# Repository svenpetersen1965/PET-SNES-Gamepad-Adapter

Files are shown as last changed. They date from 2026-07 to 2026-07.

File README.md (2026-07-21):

# PET-SNES-Gamepad-Adapter
An Adapter for connecting the SNES Gamepad to the userport of the Commodore PET/CBM/C64/VIC20

This adapter is capable of playing PETSCII robots and other SNES Gamepad compatible games on the Commodore PET. It was further tested playing the forementioned game on the C64.

There is a Rev. 1, which can be switched to use the +5V of the C64 User Port, so no diagnostic cassette dongle or external PSU is required for powering the gamepad. 

<b>!!!WARNING: Setting the power selection switch to C64 and connect the device to a PET might damage the computer!!!</b> 

It is recommended to leave the switch not populated in case you are planning to coonect the device to a PET. If you have a PET, check the setting each time, before you connect ther device to the PET. 

Recommended screws:<br>
Four each of 2.9mm x 9.5mm (self taping) screws for sheet metal (C 2,9x9,5H, DIN 7981).

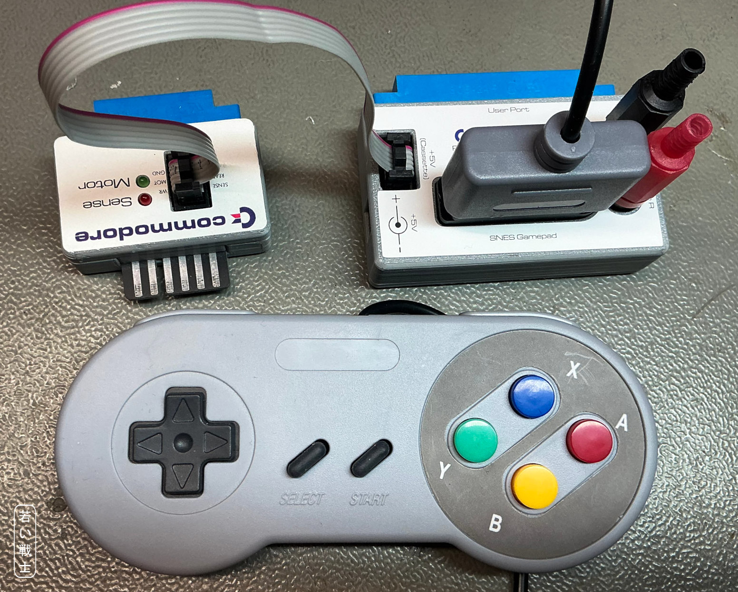
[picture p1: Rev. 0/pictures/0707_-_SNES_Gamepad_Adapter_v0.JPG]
PET SNES Gamepad Adapter Rev.0


The BOM value of Rev. 1 is 14,95€ (2026-07-21) without the cassette dongle, a case and or shipping fees or tariffs .

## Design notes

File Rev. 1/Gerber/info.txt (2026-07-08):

      
       Board: PET_SNES_Gamepad
       Rev.:  1
  
       Files:
       ======
  
       All Gerber files are generated in extended gerber format (RS274X)
       *.TOP        : Film top copper
       *.BOT        :  -"- bottom copper
       *.STC        :  -"- top soldermask 
       *.STS        :  -"- bottom soldermask
       *.PLC        :  -"- silk screen top
       *.PLS        :  -"- silk screen bottom 
       *.DK         : Drills plated Through (Excellon)
       *.NDK        : Drills not plated Through (Excellon)
       *.OUT        : Board outline

       Board Size:
       ===========
       Length     :   71.0 mm
       Width      :   43.0 mm
       Thickness  :   1.6 mm
       Material   :   FR 4
       Copper     :   35 um
       Surface    :   HASL
       
       Remarks:
       ========
       Width >= 8mil
       Distance >= 6mil
       Drill >= 0.35mm

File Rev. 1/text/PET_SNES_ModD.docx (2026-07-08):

SNES Gamepad Adapter for Commodore PET Rev.1

Module Description

# Introduction

The SNES Gamepad Adapter for PET works with the respective games found on Bo Zimmerman’s website zimmers.net and PETSCII robots by the 8bit guy.

The source of information about the hardware requirements is the file snes_adapter.zip from zimmers.net (https://www.zimmers.net/anonftp/pub/cbm/documents/projects/interfaces/index.html). A further source was https://wiki.superfamicom.org/schematics-ports-and-pinouts#. The zimmers.net file contains references to texelex.com and Steve Lewis plus source code in C and BASIC for polling the gamepad.

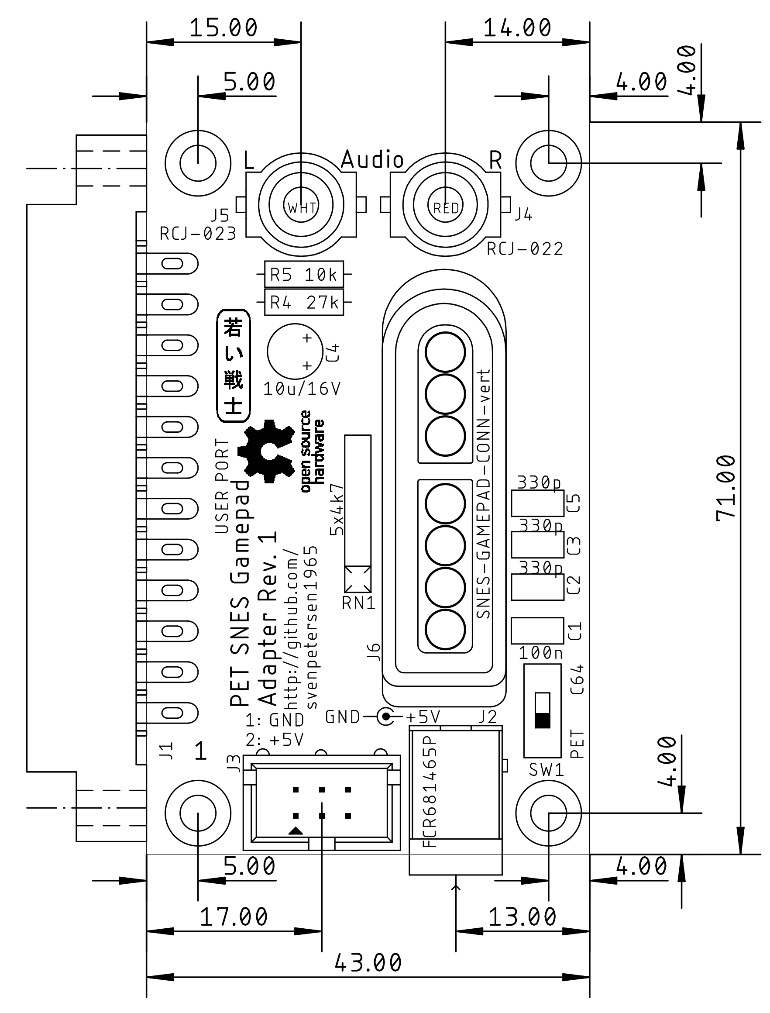
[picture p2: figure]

Figure 1: PET SNES Gamepad Adapter Rev. 0 (Dimensions)

Since the PET User Port does not provide +5V supply voltage, there is a 6 was box pin header form connecting a cassette port dongle (https://github.com/svenpetersen1965/C64-Diagnostic-Rev.-586220-Harness/tree/master/Diag586220_Harness/Diag586220_Cassette_Port) (where +5V can be tapped for the Gamepad. This is the recommended solution. Further, there is a 5.5mm/2.1mm barrel connector for a +5V external PSU. For the C64, the switch SW1 can be set to “C64” to use the +5V from the C64 User Port.

WARNING: Never connect to board to a PET with SW1 in the C64 position, since this might cause damage to the PET.

The CB2 audio is tapped from the user port and connected to two RCA jacks via a voltage divider and a capacitor for connecting external PC speakers.

The adapter works with PETSCII Robots for the C64, as well. Since the 5V of the C64 are not connected (that would be the TVVIDEO pin of the user port), either a Cassette Port Dongle or an external Power Supply is required.

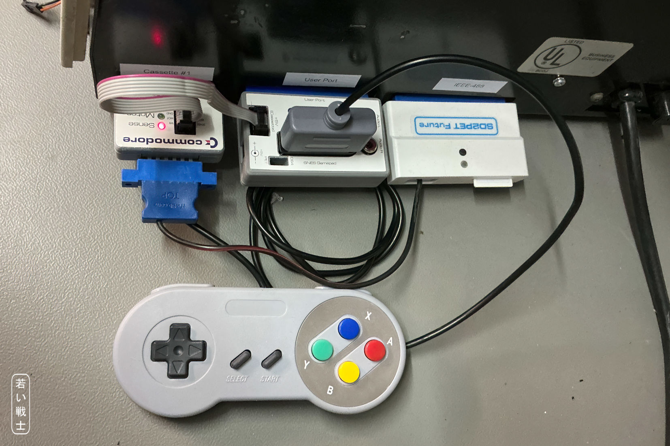
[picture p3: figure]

Figure 2: Backside of a CBM8032 - SNES Adapter with Cassette Port Dongle (and SD2PET Future)

# Switch SW1

Since connecting the PET SNES Gamepad Adapter to a PET, while SW1 is set to “C64” can damage the PET, it should be considered well, if SW1 is installed.

SW1 is for using the +5V from the C64 User Port instead of the diagnostic cassette dongle or an external +5V power supply. If SW1 is not placed, the board works exactly like Rev. 0 (with the previously mentioned options for the supply voltage and a Rev. 0 case). It is recommended to install the switch only, in case the adapter is used only with a C64.

# Pinouts

## J1- User Port

2x12 Edge Connector, 3.96mm pitch

Pin | Signal | Gamepad
1, 12, A, N | GND | GND
3 | +5V | C64 only: +5V
F | PA3 | Clock
J | PA5 | Latch
K | PA6 | Data

## 2 – Power Supply Connector

5,5mm/2,5mm barrel connector (Cliff FCR681465P)

Pin | Signal
Center | +5VDC
Shaft | GND

This is an alternative power connector, which can be used with an external +5V power supply. It is not the preferred way of powering the module.

## J3 - Power connector (from cassette port)

2x3 pin box connector

Signal | Pin | Pin | Signal
GND | 1 | 2 | +5V
- | 3 | 4 | -
- | 5 | 6 | -

Powering from cassette port is the preferred way, since it switches off together with the PET. This requires a Cassette Port Dongle (see C64 Diagnostic harness (https://github.com/svenpetersen1965/C64-Diagnostic-Rev.-586220-Harness)).

## J4, J5 – Audio RCA jacks

2 vertical RCA jacks

Connector | Color | Center | Ring | Type
J4 | Red | Audio | GND | CUI Inc. RCJ-022
J5 | White | Audio | GND | CUI Inc. RCJ-023

Note: The CUI Inc connectors are pretty wide spread and available from Mouser and Digikey etc. There are acceptable and cheaper connectors from AliExpress, which perfectly fit into the footprint. Click URL (https://de.aliexpress.com/item/1005004200016377.html)

Both connectors are connected to the same source. The audio level is about 1.23V~ (+4dBu).

## J6 – SNES Gamepad

SNES Gamepad Connector (vertical)

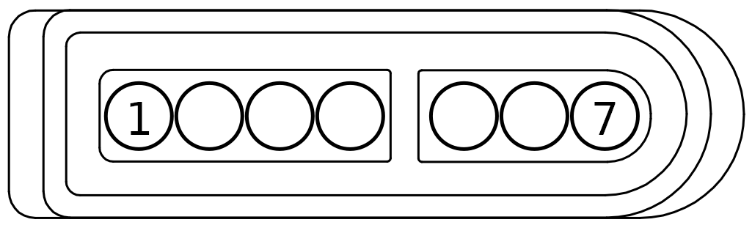
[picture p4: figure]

Figure 3: SNES Gamepad Connector

Pin | Signal
1 | +5V
2 | Clock
3 | Latch
4 | Data1
5 | Data2 (not connected)
6 | IOBIT (not connected)
7 | GND

# Case

There is a 3D printed case and a case label for Rev. 1. In case SW1 is not placed, please use case and label for the PCB Rev. 0

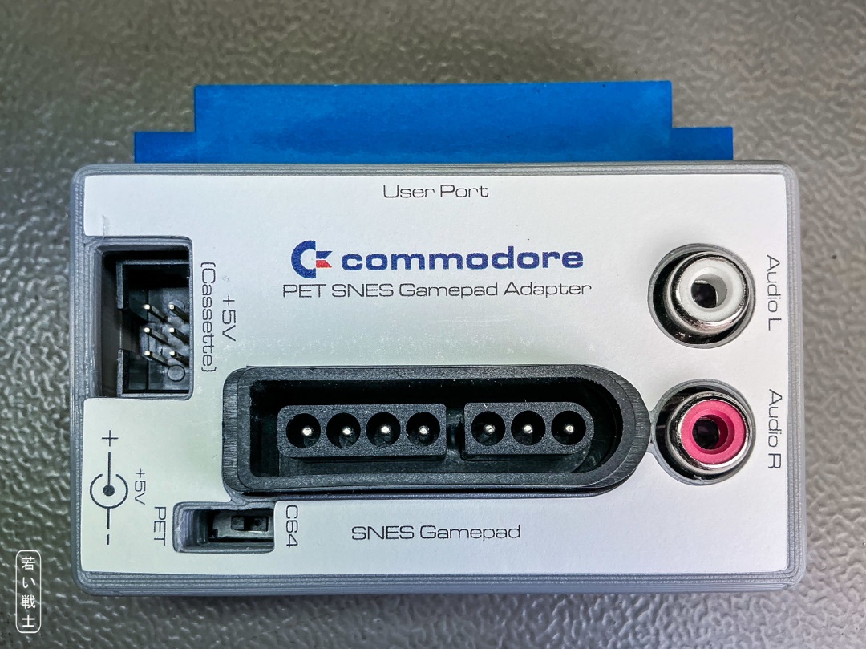
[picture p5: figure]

Figure 4: PET SNES Gamepad Adapter (in case)

# Programming Hints

First, the data direction register of the user port needs to be set correctly. Clock (bit #3) and Latch (bit#5) are outputs of the user port, Data (bit#6) is an input:

POKE 59459,8+32

While scanning the gamepad, a (positive) latch pulse is required first:

POKE59457,32:POKE59457,0:REM LATCH PULSE

The gamepad outputs a 12 bit word, MSB first. After the latch pulse, the MSB is present at the data input (bit#6) of the user port.

GW=0:B=2048
FOR I=12 TO 1 STEP-1
IF PEEK(59457) AND 64 THEN GW=GW+B:REM IS BIT#6 SET?
B=B/2
POKE59457,8:POKE59457,0:REM PULSE CLOCK
NEXT I

An active data bit is LOW, this is, why it needs to be inverted

GW=4096 + NOT GW:REM INVERT GW

Now, the gamepad word can be decoded:

Bit | Bit Value | Gamepad
0 | 1 | Fire-R
1 | 2 | Fire-L
2 | 4 | X
3 | 8 | A
4 | 16 | Right
5 | 32 | Left
6 | 64 | Down
7 | 128 | Up
8 | 256 | Start
9 | 512 | Select
10 | 1024 | Y
11 | 2048 | B

The source is SNES TEST.BAS.PRG from the previously mentioned file snes_adapter.zip

# Revision History

## Rev. 0

Prototype, tested ok

## Rev. 1

- SW1 for switching on the +5V from the C64 User Port.

PET_SNES_ModD.docx 08.07.2026 15:50 Drafted by Sven Petersen Page 2 of 2 Doc.-No.: 221-6-01-01

PET_SNES_ModD.docx 08.07.2026 15:50 Drafted by Sven Petersen Page 1 of 1 Doc.-No.: 221-6-01-01

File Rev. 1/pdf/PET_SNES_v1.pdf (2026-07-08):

# Project Documentation

## PET SNES Gamepad Adapter

## Project number: 221

## Revision: 1

## Date: 10.05.2026

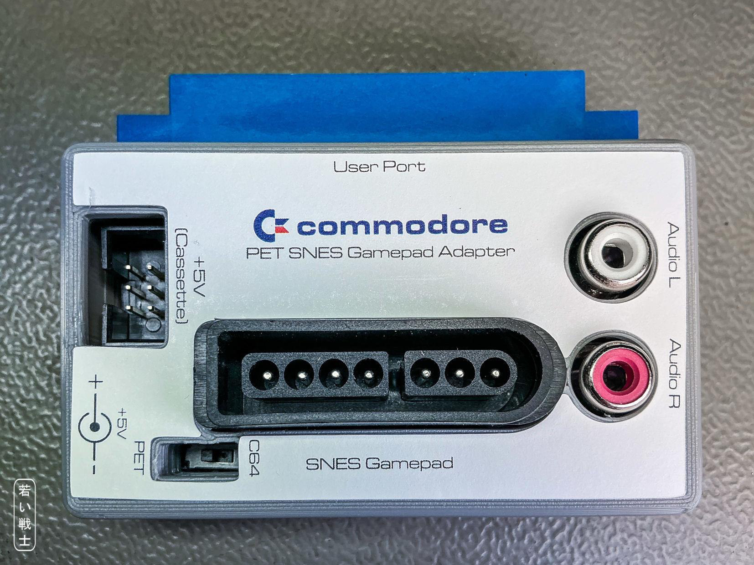
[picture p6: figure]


PET_SNES_ModD.docx | | 08.07.2026 15:50
Drafted by Sven Petersen | Page 1 of 5 | Doc.-No.: 221-6-01-01

### SNES Gamepad Adapter for Commodore PET Rev.1

### Module Description

## Introduction

The SNES Gamepad Adapter for PET works with the respective games found on Bo Zimmerman’s website zimmers.net and PETSCII robots by the 8bit guy.

The source of information about the hardware requirements is the file snes_adapter.zip from zimmers.net. (https://www.zimmers.net/anonftp/pub/cbm/documents/projects/interfaces/index.html) A further source was https://wiki.superfamicom.org/schematics-ports-and-pinouts#. (https://wiki.superfamicom.org/schematics-ports-and-pinouts) The zimmers.net file contains references to texelex.com and Steve Lewis plus source code in C and BASIC for polling the gamepad.

Figure 1: PET SNES Gamepad Adapter Rev. 0 (Dimensions)

Since the PET User Port does not provide +5V supply voltage, there is a 6 was box pin header form connecting a cassette port dongle (https://github.com/svenpetersen1965/C64-Diagnostic-Rev.-586220-Harness/tree/master/Diag586220_Harness/Diag586220_Cassette_Port) (where +5V can be tapped for the Gamepad. This is the recommended solution. Further, there is a 5.5mm/2.1mm barrel connector for a +5V external PSU.
For the C64, the switch SW1 can be set to “C64” to use the +5V from the C64 User Port.

WARNING: Never connect to board to a PET with SW1 in the C64 position, since this might cause damage to the PET.

The CB2 audio is tapped from the user port and connected to two RCA jacks via a voltage divider and a capacitor for connecting external PC speakers.

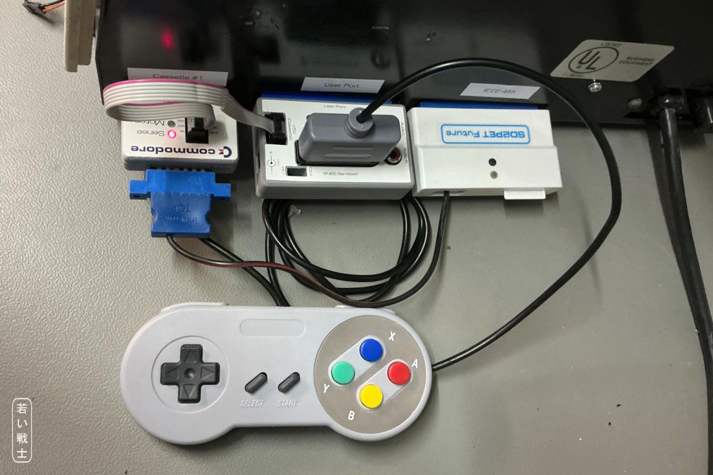
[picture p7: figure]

PET_SNES_ModD.docx | | 08.07.2026 15:50
Drafted by Sven Petersen | Page 2 of 5 | Doc.-No.: 221-6-01-01

The adapter works with PETSCII Robots for the C64, as well. Since the 5V of the C64 are not connected (that would be the TVVIDEO pin of the user port), either a Cassette Port Dongle or an external Power Supply is required.

Figure 2: Backside of a CBM8032 - SNES Adapter with Cassette Port Dongle (and SD2PET Future)

## Switch SW1

### Since connecting the PET SNES Gamepad Adapter to a PET, while SW1 is set to “C64” can

damage the PET, it should be considered well, if SW1 is installed.

SW1 is for using the +5V from the C64 User Port instead of the diagnostic cassette dongle or an external +5V power supply. If SW1 is not placed, the board works exactly like Rev. 0 (with the previously mentioned options for the supply voltage and a Rev. 0 case). It is recommended to install the switch only, in case the adapter is used only with a C64.

## Pinouts

### J1- User Port

2x12 Edge Connector, 3.96mm pitch

Pin | Signal | Gamepad
1, 12, A, N | GND | GND
3 | +5V | C64 only: +5V
F | PA3 | Clock
J | PA5 | Latch
K | PA6 | Data

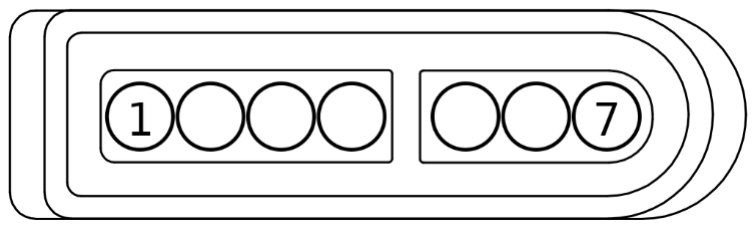
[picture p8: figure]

PET_SNES_ModD.docx | | 08.07.2026 15:50
Drafted by Sven Petersen | Page 3 of 5 | Doc.-No.: 221-6-01-01

### 2 – Power Supply Connector

5,5mm/2,5mm barrel connector (Cliff FCR681465P)

Pin | Signal
Center | +5VDC
Shaft | GND
This is an alternative power connector, which can be used with an external +5V power supply. It is not the preferred way of powering the module.

### J3 - Power connector (from cassette port)

2x3 pin box connector

Signal Pin | Pin Signal
GND | 1 | 2 | +5V
- | 3 | 4 | -
- | 5 | 6 | -

Powering from cassette port is the preferred way, since it switches off together with the PET. This requires a Cassette Port Dongle (see C64 Diagnostic harness). (https://github.com/svenpetersen1965/C64-Diagnostic-Rev.-586220-Harness)

### J4, J5 – Audio RCA jacks

2 vertical RCA jacks

Connector | Color | Center | Ring | Type
J4 | Red | Audio | GND | CUI Inc. RCJ-022
J5 | White | Audio | GND | CUI Inc. RCJ-023

Note: The CUI Inc connectors are pretty wide spread and available from Mouser and Digikey etc. There are acceptable and cheaper connectors from AliExpress, which perfectly fit into the footprint. Click URL (https://de.aliexpress.com/item/1005004200016377.html)

Both connectors are connected to the same source. The audio level is about 1.23V~ (+4dBu).

### J6 – SNES Gamepad

SNES Gamepad Connector (vertical)

Figure 3: SNES Gamepad Connector

Pin | Signal
1 | +5V
2 | Clock
3 | Latch
4 | Data1
5 | Data2 (not connected)
6 | IOBIT (not connected)
7 | GND

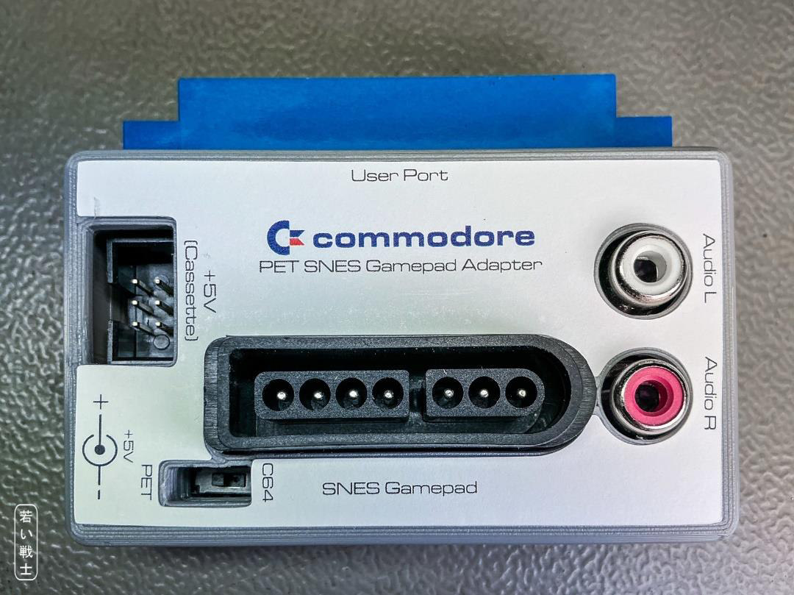
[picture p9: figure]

PET_SNES_ModD.docx | | 08.07.2026 15:50
Drafted by Sven Petersen | Page 4 of 5 | Doc.-No.: 221-6-01-01

## Case

There is a 3D printed case and a case label for Rev. 1. In case SW1 is not placed, please use case and label for the PCB Rev. 0

Figure 4: PET SNES Gamepad Adapter (in case)

## Programming Hints

First, the data direction register of the user port needs to be set correctly. Clock (bit #3) and Latch (bit#5) are outputs of the user port, Data (bit#6) is an input:

POKE 59459,8+32

While scanning the gamepad, a (positive) latch pulse is required first:

POKE59457,32:POKE59457,0:REM LATCH PULSE

The gamepad outputs a 12 bit word, MSB first. After the latch pulse, the MSB is present at the data input (bit#6) of the user port.

GW=0:B=2048
FOR I=12 TO 1 STEP-1
IF PEEK(59457) AND 64 THEN GW=GW+B:REM IS BIT#6 SET? B=B/2
POKE59457,8:POKE59457,0:REM PULSE CLOCK
NEXT I

PET_SNES_ModD.docx | | 08.07.2026 15:50
Drafted by Sven Petersen | Page 5 of 5 | Doc.-No.: 221-6-01-01

An active data bit is LOW, this is, why it needs to be inverted

GW=4096 + NOT GW:REM INVERT GW

Now, the gamepad word can be decoded:

Bit | Bit Value | Gamepad
0 | 1 | Fire-R
1 | 2 | Fire-L
2 | 4 | X
3 | 8 | A
4 | 16 | Right
5 | 32 | Left
6 | 64 | Down
7 | 128 | Up
8 | 256 | Start
9 | 512 | Select
10 | 1024 | Y
11 | 2048 | B

The source is SNES TEST.BAS.PRG from the previously mentioned file snes_adapter.zip

## Revision History

### Rev. 0

Prototype, tested ok

### Rev. 1

- SW1 for switching on the +5V from the C64 User Port.

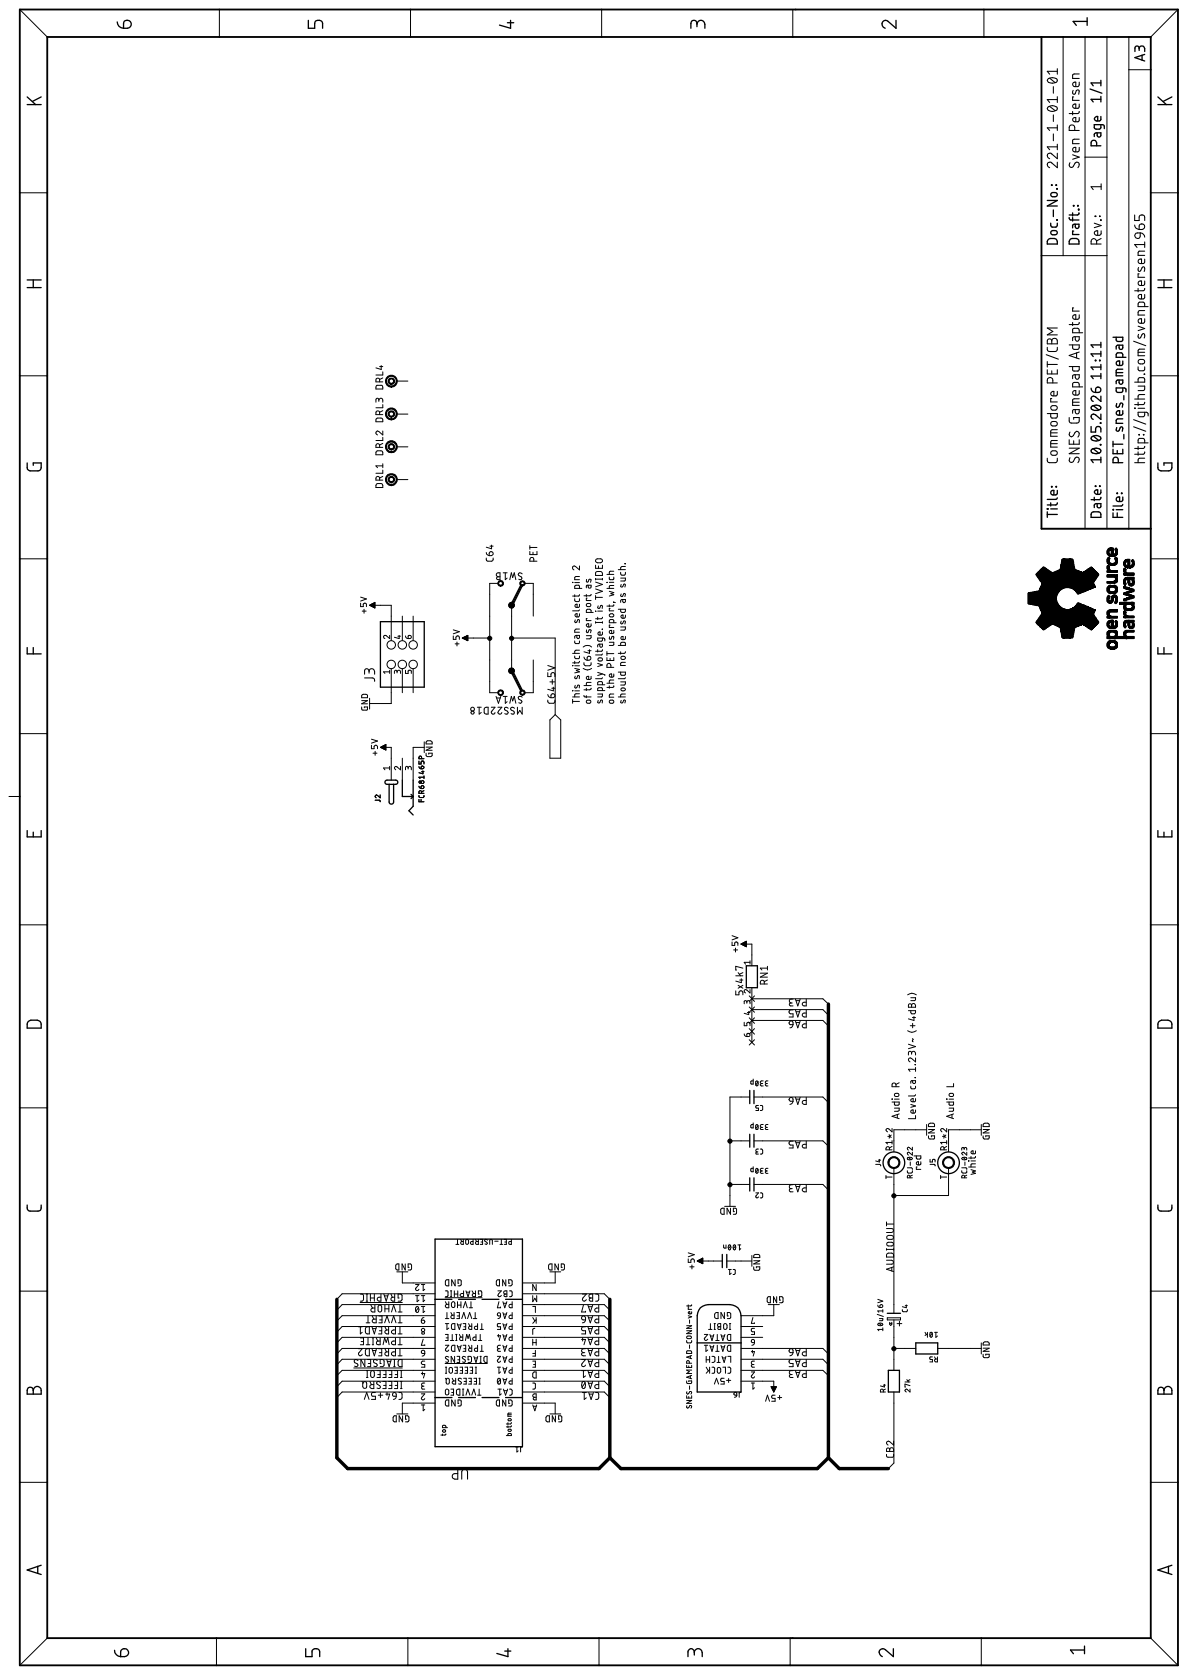
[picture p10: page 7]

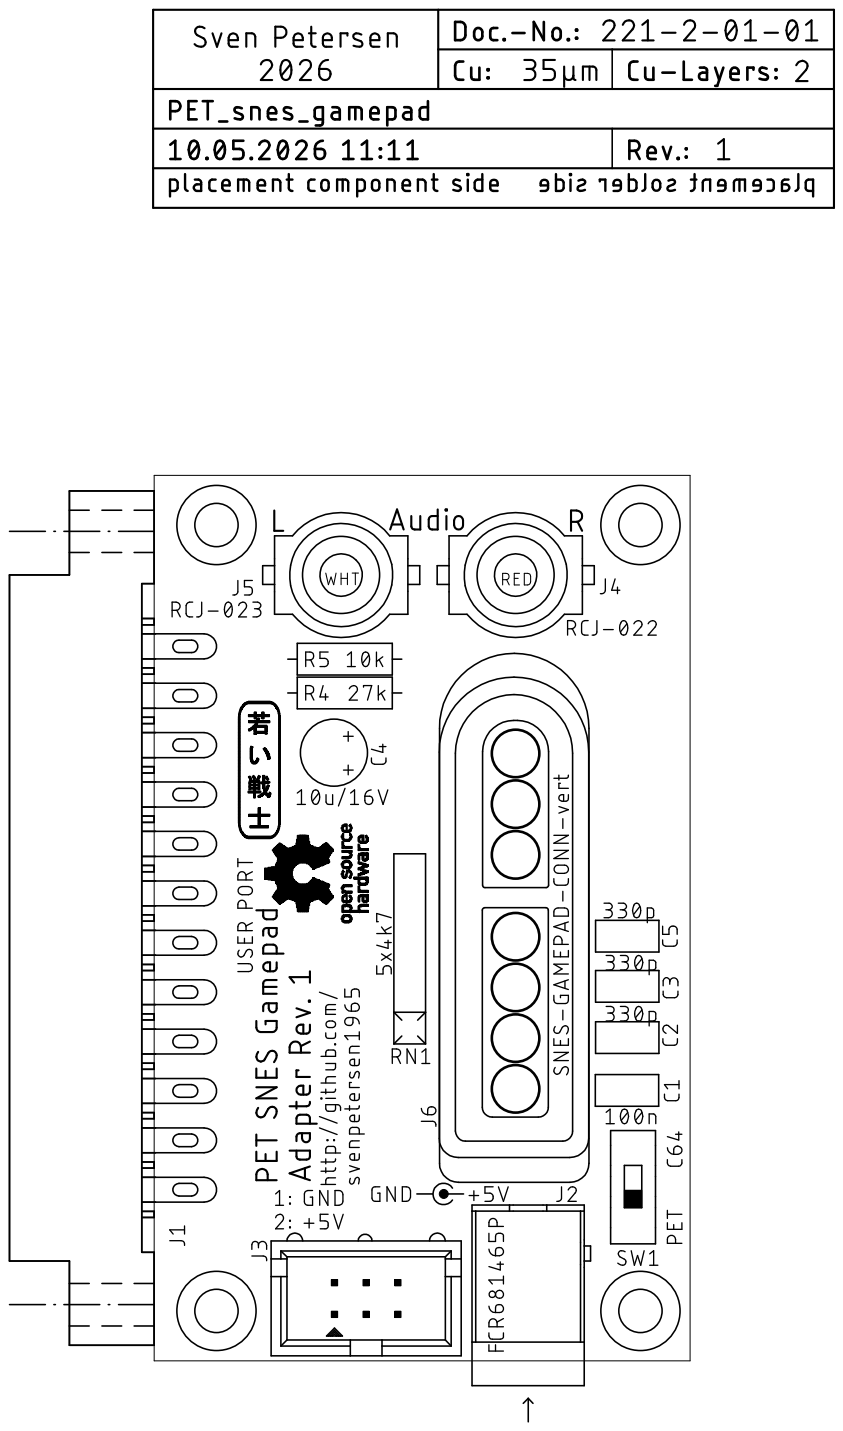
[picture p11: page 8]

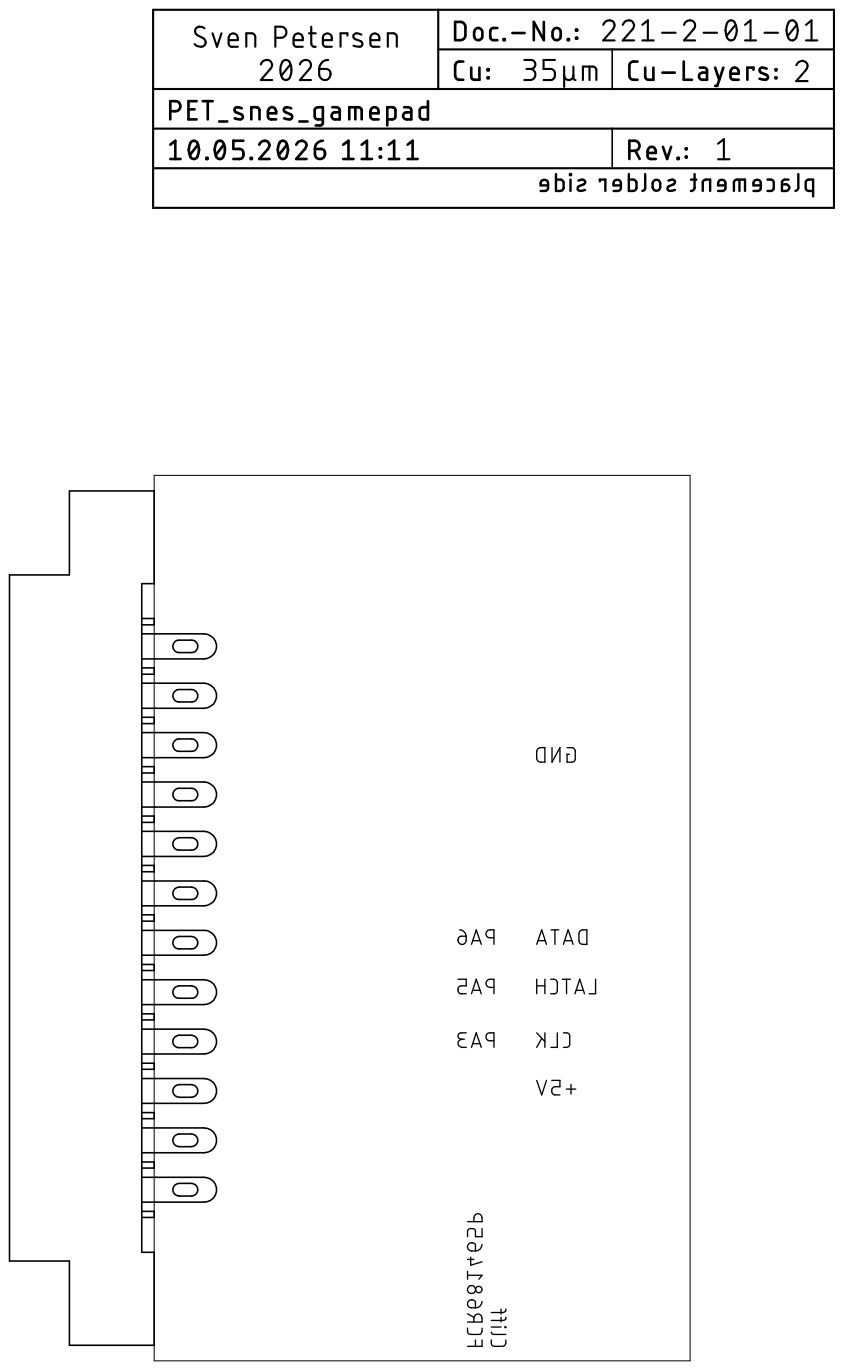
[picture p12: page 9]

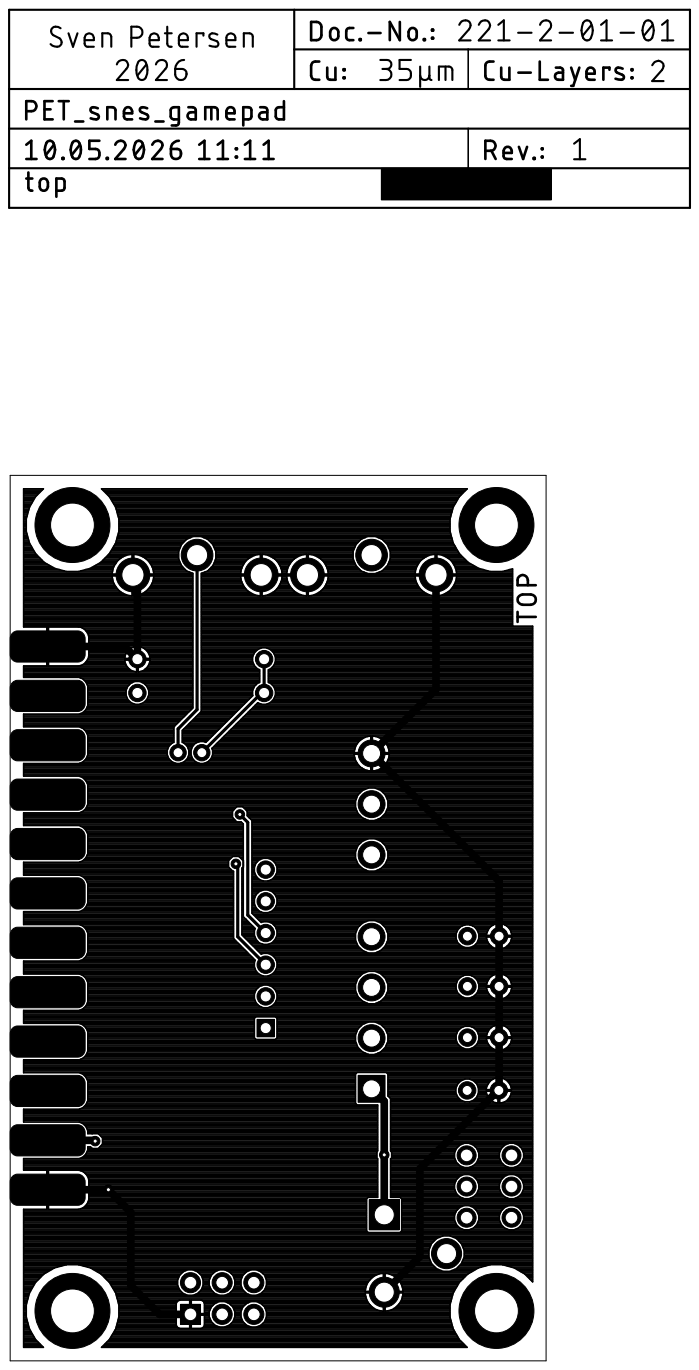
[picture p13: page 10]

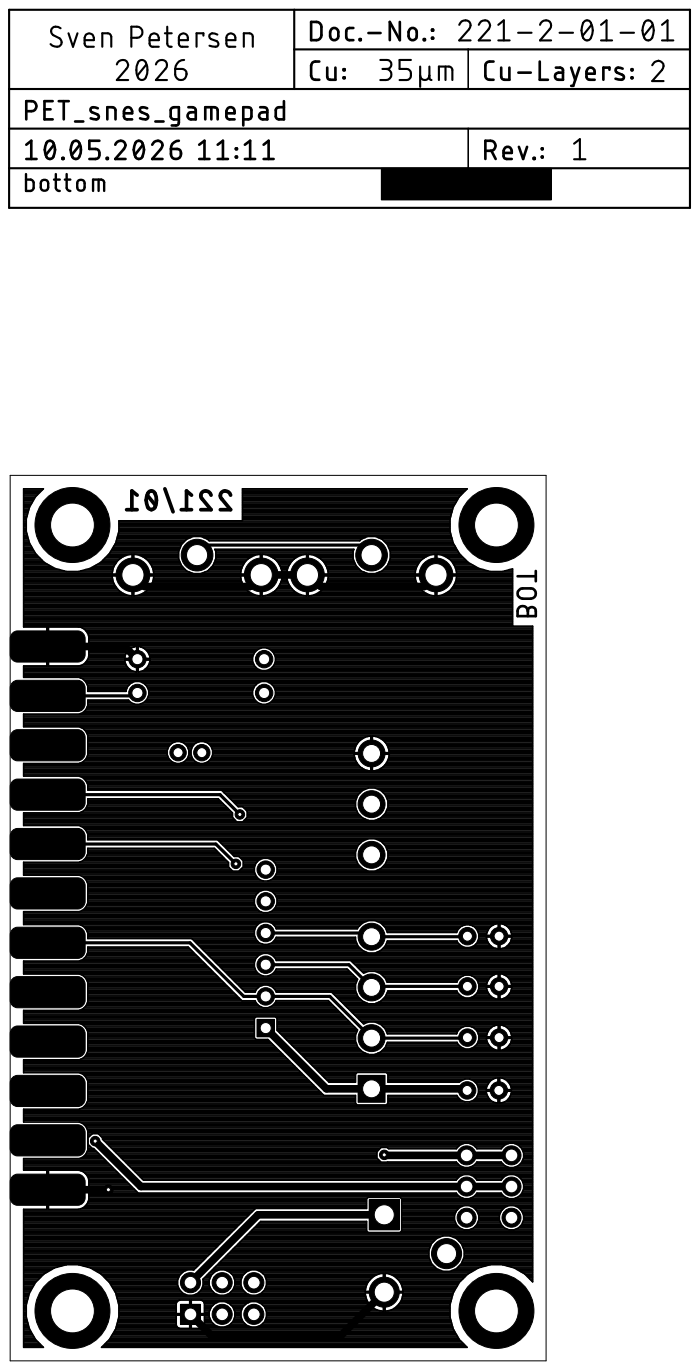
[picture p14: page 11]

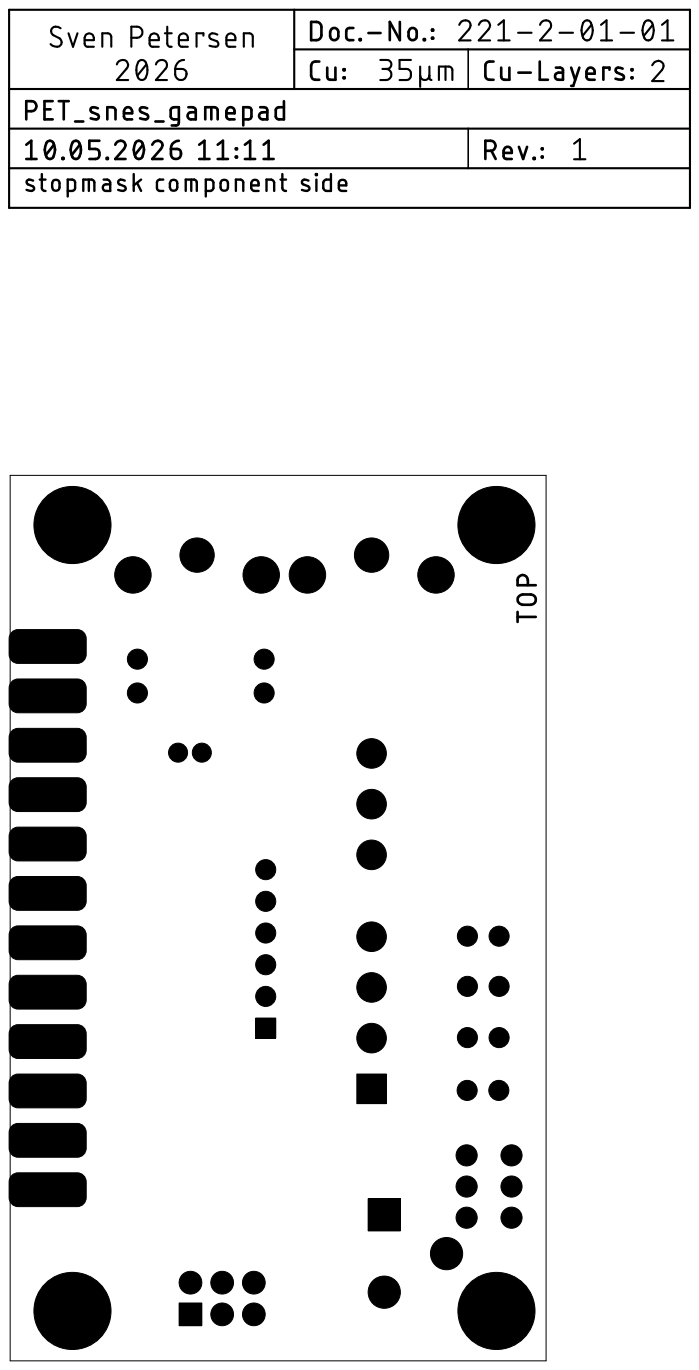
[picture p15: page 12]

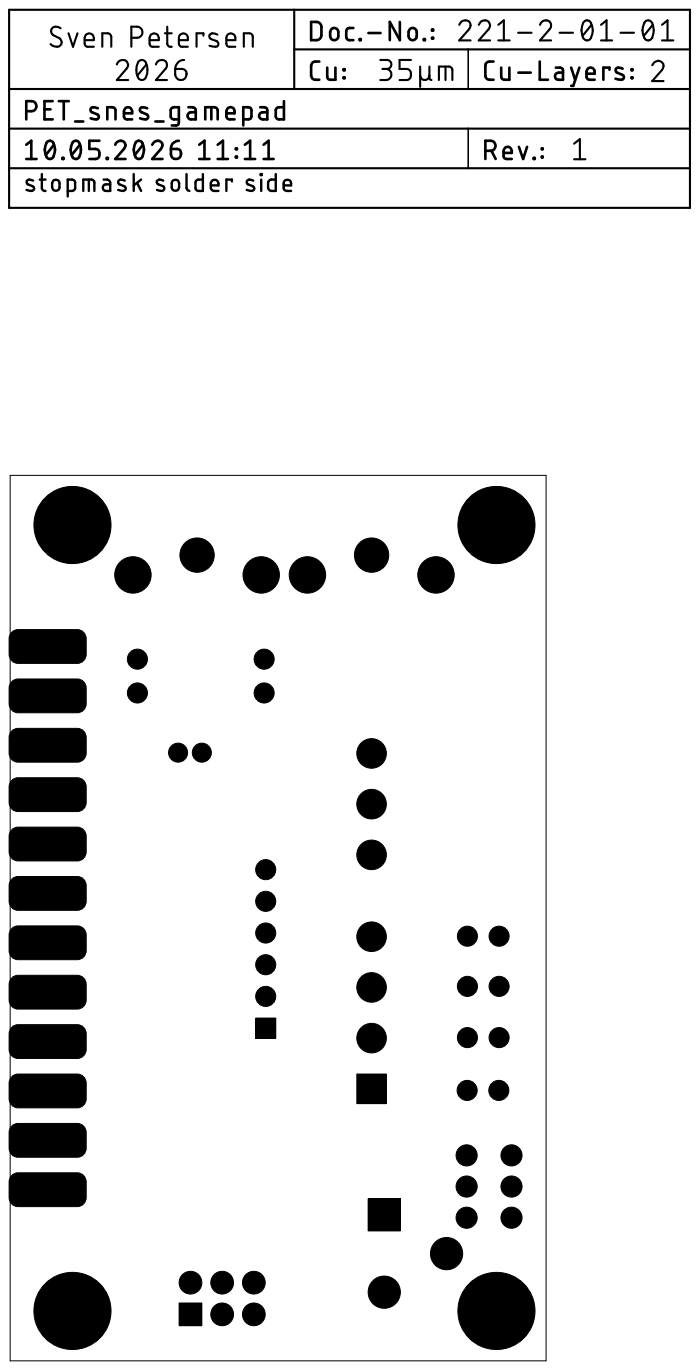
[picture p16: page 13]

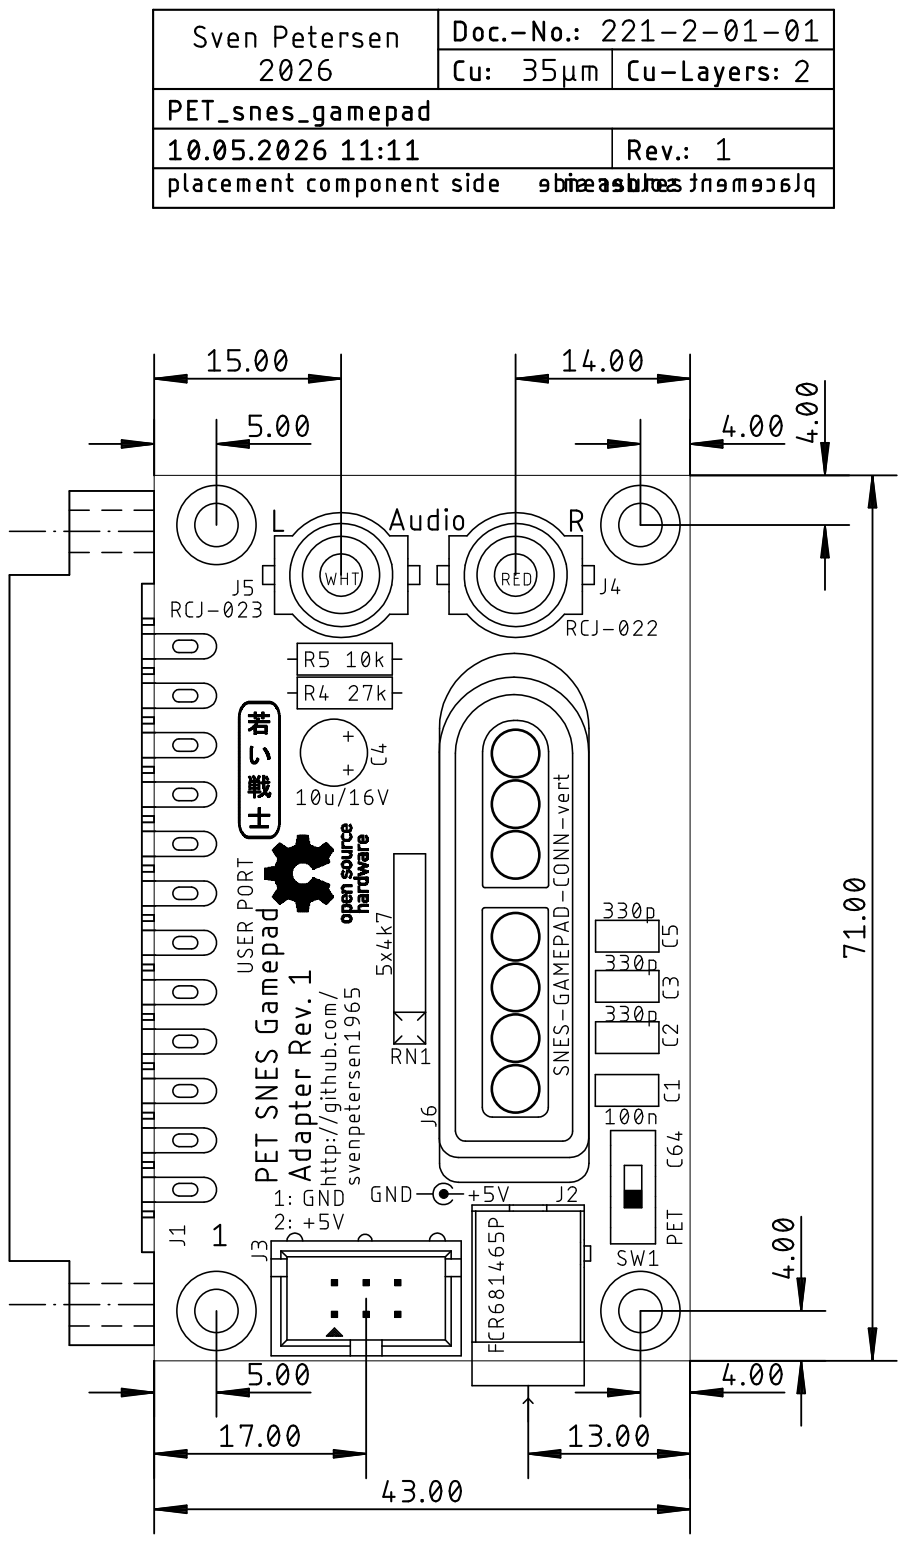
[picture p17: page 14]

PET_SNES_Test.docx | | 08.07.2026 15:50
Drafted by Sven Petersen | Page 1 of 5 | Doc.-No.: 221-6-02-01

### SNES Gamepad Adapter for Commodore PET Rev.1

### Testing

## Test Setup

- PET SNES Gamepad Adapter Rev. 1
- Diagnostic Cassette Port Dongle & 6-way ribbon cable
- A SNES Gamepad (non USB version)
- Commodore CBM3016
- Commodore CBM8032
- Commodore C64

### - Software “SNES TEST.BAS.PRG” from zimmers.net (in snes_adapter.zip, see module

description
- Software “PETROBOTS12.D64” (PETSCII Robots paid version from The 8bit-Guy) (https://www.the8bitguy.com/product-category/games/)

The PET SNES Gamepad Adapter was connected to the user port of the respective computer. The Gamepad was connected to the device under test.

Figure 1: The PET SNES Gamepad Adapter, powered by cassette port and an SD2PET Future with the required software

## Test Execution

### Testing The Readout of The Gamepad

The computer is the CBM8032, the software is SNES TEST.BAS.PRG. The program was stored on the SD2PET SD card. Loaded and started.

Every button was pressed on the gamepad. The software has display each of that properly.

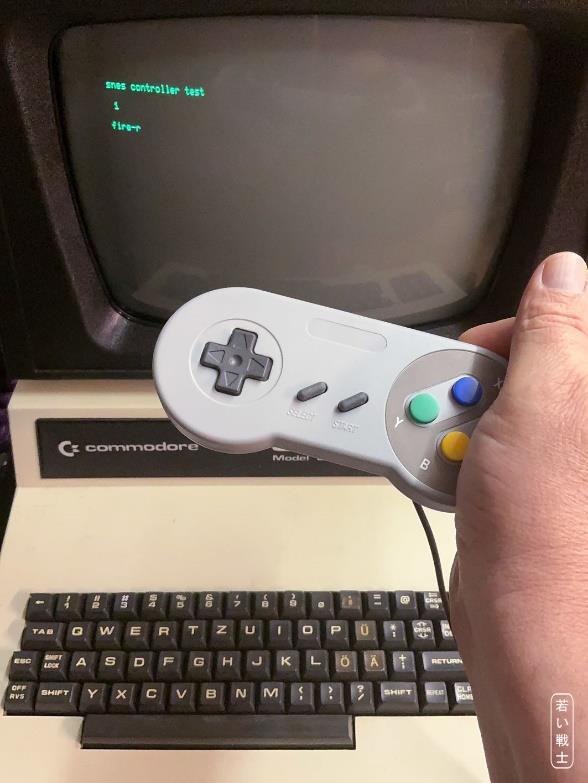
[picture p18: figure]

PET_SNES_Test.docx | | 08.07.2026 15:50
Drafted by Sven Petersen | Page 2 of 5 | Doc.-No.: 221-6-02-01

Figure 2: SNEST TEST.BAS.PRG on CB8032

### PETSCII Robots on CBM8032

Due to memory size, the PETSCII Robots software was run on the CBM8032, which had to be set to 40 columns previously.

As a game controller, the SNES Gamepad was selected.

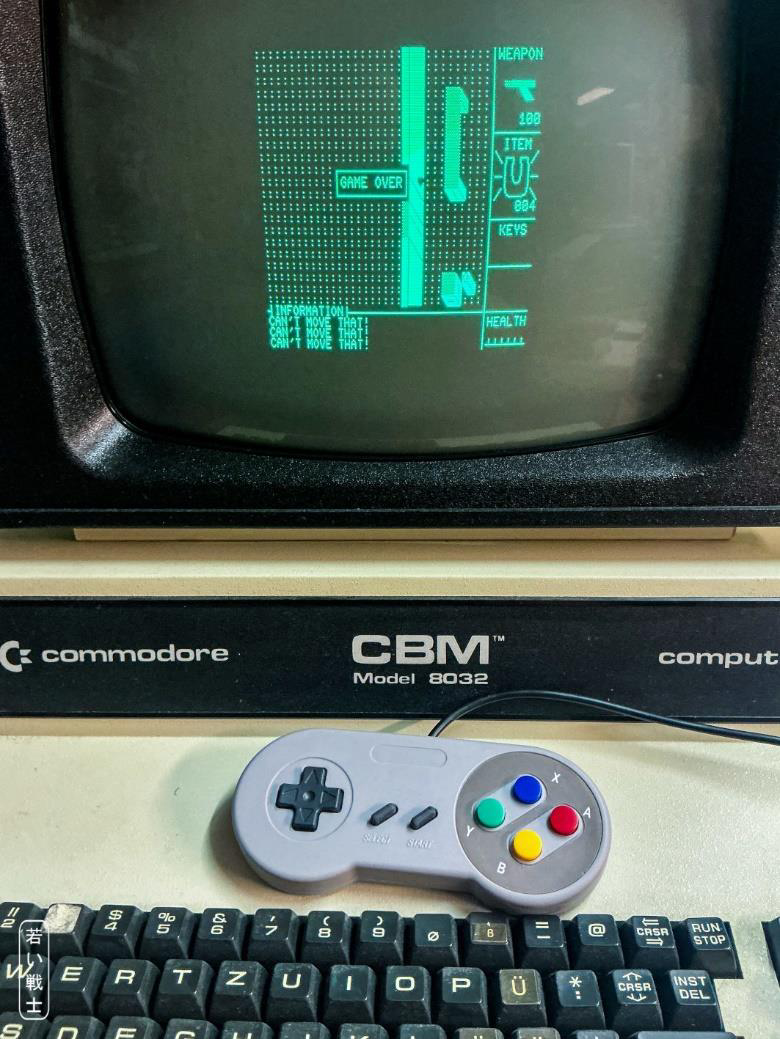
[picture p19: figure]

PET_SNES_Test.docx | | 08.07.2026 15:50
Drafted by Sven Petersen | Page 3 of 5 | Doc.-No.: 221-6-02-01

Figure 3: PETSCII Robots on the CBM8032

The software reacted properly to the SNES Gamepad.

### PETSCII Robots on C64

The Gamepad was connected to the C64 via the device under test. A cassette dongle was required
to power the gamepad. The software was run from the disk image “C64Robots v1.3.d64”, which
was part of the PETSCII Robots purchase.

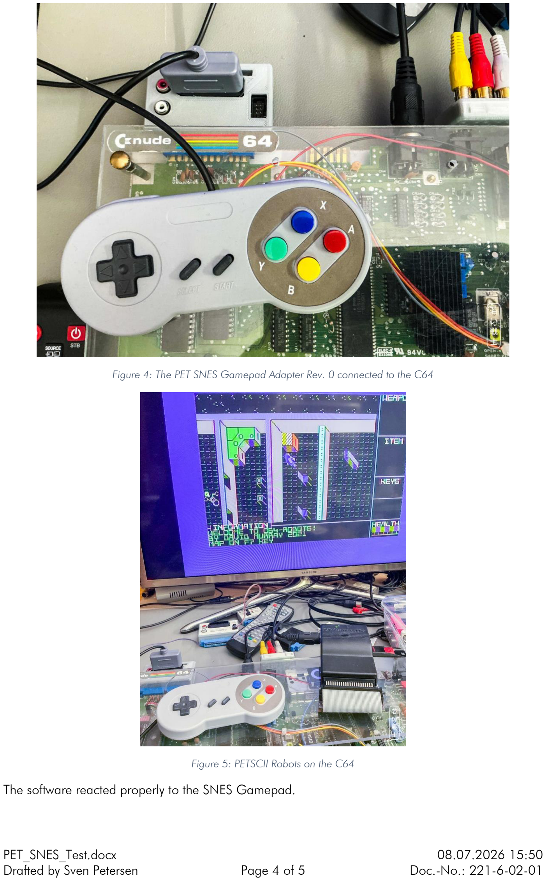
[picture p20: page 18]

PET_SNES_Test.docx | | 08.07.2026 15:50
Drafted by Sven Petersen | Page 4 of 5 | Doc.-No.: 221-6-02-01

Figure 4: The PET SNES Gamepad Adapter Rev. 0 connected to the C64

Figure 5: PETSCII Robots on the C64

The software reacted properly to the SNES Gamepad.

PET_SNES_Test.docx | | 08.07.2026 15:50
Drafted by Sven Petersen | Page 5 of 5 | Doc.-No.: 221-6-02-01

## Conclusion

The PET SNES Gamepad Adapter Rev. 1 is working properly.

Pos. Qty Value Footprint Ref.-No. Comment

1 1 221-2-01-00 2 Layer _PCB Rev. 0 2 layer, Cu 35µ, HASL, 71.0mm x 43.0mm, 1.6mm FR4

2 1 100n C-2,5 C1 ceramic capacitor, pitch: 2.5mm

3 3 330p C-2,5 C2, C3, C5 ceramic capacitor, pitch: 2.5mm

4 1 10u/16V C5,0/2,0 C4 aluminum electrolytic, ∅5.0mm/pitch 2.0mm 105°C,

l=11mm, e.G. Reichelt RD1C106M05011180 . Lay flat on

board.

5 1 Edge connector, 2x12,

3.96mm

USERPORT J1 edge connector, C64 user port, Ali Express, "series 805" or

other

6 1 FCR681465P FCR681465P J2 Cliff. 2,5mm/5.5mm barrel connector. E.g. Reichelt CLIFF

FCR681465P

7 1 2x3 box header, 2.54mm 2X03WV J3 e.g. Reichelt WSL 6G.

8 1 RCJ-022 RCJ-02X J4 CUI Inc., RCA jack, vertical, red. Mouser: 490-RCJ-022,
Digikey: CP-1407-ND. Alternative part: Keystone 577

9 1 RCJ-023 RCJ-02X J5 CUI Inc., RCA jack, vertical, white. Mouser: 490-RCJ-023,
Digikey: CP-1408-ND. Alternative part: Keystone 584

10 1 SNES-GAMEPAD-CONN-

# vert SNES_GAMEPAD _VERT J6 Vertical SNES Gamepad Connector from Ali Express

11 1 27k R-10 R4 1/4W, 1% or better

12 1 10k R-10 R5 1/4W, 1% or better

13 1 5x4k7 RN-6 RN1 Resistor network 4 pin, 5 resistors

14 1 mini slide switch, 2.54mm,

DPDT, through hole

DPDT_9MM SW1 Ali Express, ebay, Amazon, search term "MSS22D18"

## PET SNES Gamepad Adapter Rev. 1

## Bill of Material Rev. 1.0

PET_SNES_BOM_v1_0.xlsx

Drafted by Sven Petersen Page 1 of 1

08.07.2026 15:56
Doc.No.: 221-5-01-01.0

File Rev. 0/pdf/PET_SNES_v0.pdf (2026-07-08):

# Project Documentation

## PET SNES Gamepad Adapter

## Project number: 221

## Revision: 0

## Date: 04.01.2025

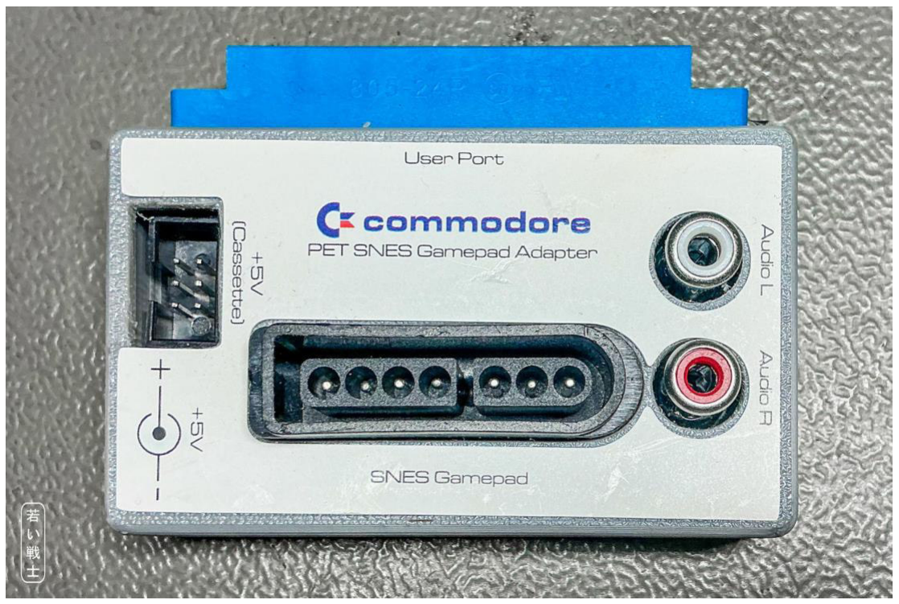
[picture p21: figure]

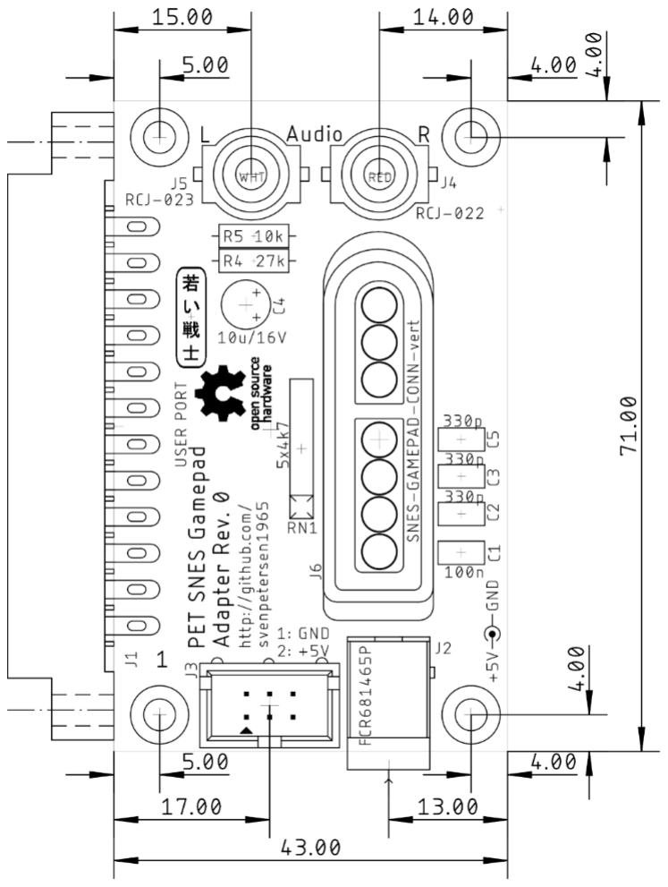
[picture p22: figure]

PET_SNES_ModD.docx | | 05.07.2026 16:54
Drafted by Sven Petersen | Page 1 of 5 | Doc.-No.: 221-6-01-00

### SNES Gamepad Adapter for Commodore PET Rev.0

### Module Description

## Introduction

The SNES Gamepad Adapter for PET works with the respective games found on Bo Zimmerman’s website zimmers.net and PETSCII robots by the 8bit guy.

The source of information about the hardware requirements is the file snes_adapter.zip from zimmers.net. (https://www.zimmers.net/anonftp/pub/cbm/documents/projects/interfaces/index.html) A further source was https://wiki.superfamicom.org/schematics-ports-and-pinouts#. (https://wiki.superfamicom.org/schematics-ports-and-pinouts) The zimmers.net file contains references to texelex.com and Steve Lewis plus source code in C and BASIC for polling the gamepad.

Figure 1: PET SNES Gamepad Adapter Rev. 0 (Dimensions)

Since the PET User Port does not provide +5V supply voltage, there is a 6 was box pin header form connecting a cassette port dongle (https://github.com/svenpetersen1965/C64-Diagnostic-Rev.-586220-Harness/tree/master/Diag586220_Harness/Diag586220_Cassette_Port) (where +5V can be tapped for the Gamepad. This is the recommended solution. Further, there is a 5.5mm/2.1mm barrel connector for a +5V external PSU.

The CB2 audio is tapped from the user port and connected to two RCA jacks via a voltage divider and a capacitor for connecting external PC speakers.

The adapter works with PETSCII Robots for the C64, as well. Since the 5V of the C64 are not connected (that would be the TVVIDEO pin of the user port), either a Cassette Port Dongle or an external Power Supply is required.

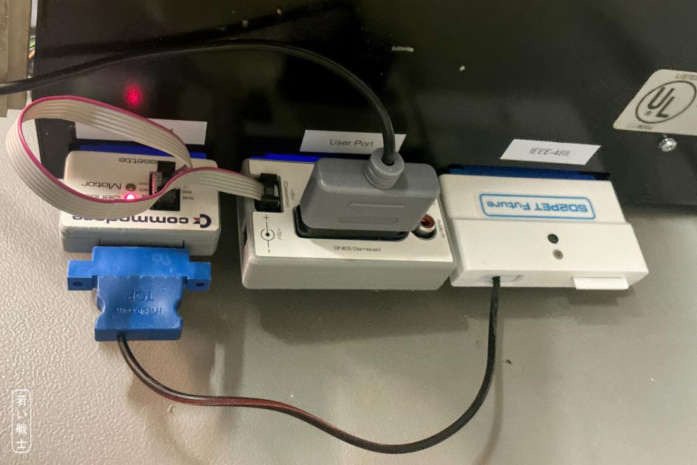
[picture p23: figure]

PET_SNES_ModD.docx | | 05.07.2026 16:54
Drafted by Sven Petersen | Page 2 of 5 | Doc.-No.: 221-6-01-00

Figure 2: Backside of a CBM8032 - SNES Adapter with Cassette Port Dongle (and SD2PET Future)

## Pinouts

### J1- User Port

2x12 Edge Connector, 3.96mm pitch

Pin | Signal | Gamepad
1, 12, A, N | GND | GND
F | PA3 | Clock
J | PA5 | Latch
K | PA6 | Data

### J2 – Power Supply Connector

5,5mm/2,5mm barrel connector (Cliff FCR681465P)

Pin | Signal
Center | +5VDC
Shaft | GND
This is an alternative power connector, which can be used with an external +5V power supply. It is not the preferred way of powering the module.

### J3 - Power connector (from cassette port)

2x3 pin box connector

Signal Pin | Pin Signal
GND | 1 | 2 | +5V
- | 3 | 4 | -
- | 5 | 6 | -


PET_SNES_ModD.docx | | 05.07.2026 16:54
Drafted by Sven Petersen | Page 3 of 5 | Doc.-No.: 221-6-01-00

Powering from cassette port is the preferred way, since it switches off together with the PET. This requires a Cassette Port Dongle (see C64 Diagnostic harness). (https://github.com/svenpetersen1965/C64-Diagnostic-Rev.-586220-Harness)

### J4, J5 – Audio RCA jacks

### 2 vertical RCA jacks

Connector | Color | Center | Ring | Type
J4 | Red | Audio | GND | CUI Inc. RCJ-022
J5 | White | Audio | GND | CUI Inc. RCJ-023

Note: The CUI Inc connectors are pretty wide spread and available from Mouser and Digikey etc. There are acceptable and cheaper connectors from AliExpress, which perfectly fit into the footprint. Click URL (https://de.aliexpress.com/item/1005004200016377.html)

Both connectors are connected to the same source. The audio level is about 1.23V~ (+4dBu).

### J6 – SNES Gamepad

SNES Gamepad Connector (vertical)

Figure 3: SNES Gamepad Connector

Pin Signal
1 +5V
2 Clock
3 Latch
4 Data1
5 Data2 (not connected)
6 IOBIT (not connected)
7 GND

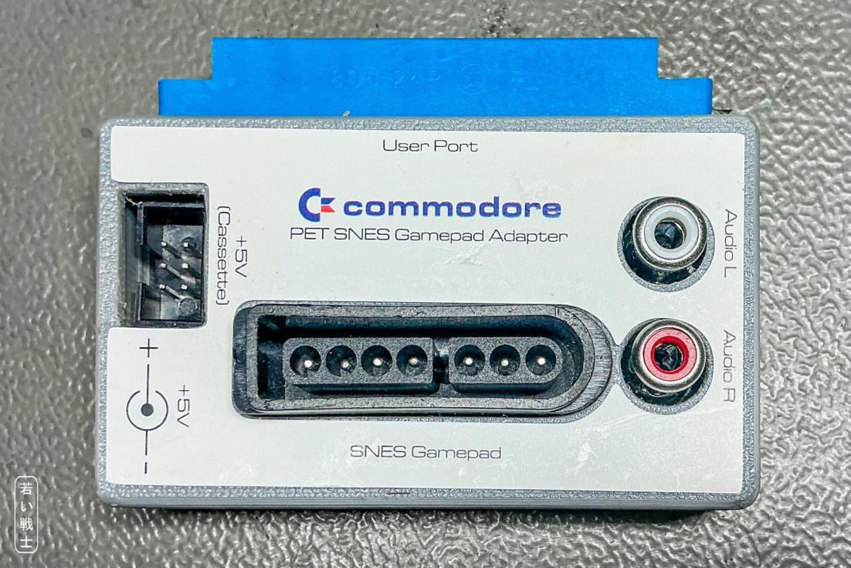
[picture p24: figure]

PET_SNES_ModD.docx | | 05.07.2026 16:54
Drafted by Sven Petersen | Page 4 of 5 | Doc.-No.: 221-6-01-00

## Case

There is a 3D printed case and a case label for this project.

Figure 4: PET SNES Gamepad Adapter (in case)

## Programming Hints

First, the data direction register of the user port needs to be set correctly. Clock (bit #3) and Latch (bit#5) are outputs of the user port, Data (bit#6) is an input:

POKE 59459,8+32

While scanning the gamepad, a (positive) latch pulse is required first:

POKE59457,32:POKE59457,0:REM LATCH PULSE

The gamepad outputs a 12 bit word, MSB first. After the latch pulse, the MSB is present at the data input (bit#6) of the user port.

GW=0:B=2048
FOR I=12 TO 1 STEP-1
IF PEEK(59457) AND 64 THEN GW=GW+B:REM IS BIT#6 SET? B=B/2
POKE59457,8:POKE59457,0:REM PULSE CLOCK
NEXT I

PET_SNES_ModD.docx | | 05.07.2026 16:54
Drafted by Sven Petersen | Page 5 of 5 | Doc.-No.: 221-6-01-00

An active data bit is LOW, this is, why it needs to be inverted

GW=4096 + NOT GW:REM INVERT GW

Now, the gamepad word can be decoded:

Bit | Bit Value | Gamepad
0 | 1 | Fire-R
1 | 2 | Fire-L
2 | 4 | X
3 | 8 | A
4 | 16 | Right
5 | 32 | Left
6 | 64 | Down
7 | 128 | Up
8 | 256 | Start
9 | 512 | Select
10 | 1024 | Y
11 | 2048 | B

The source is SNES TEST.BAS.PRG from the previously mentioned file snes_adapter.zip

## Revision History

### Rev. 0

Prototype, tested ok

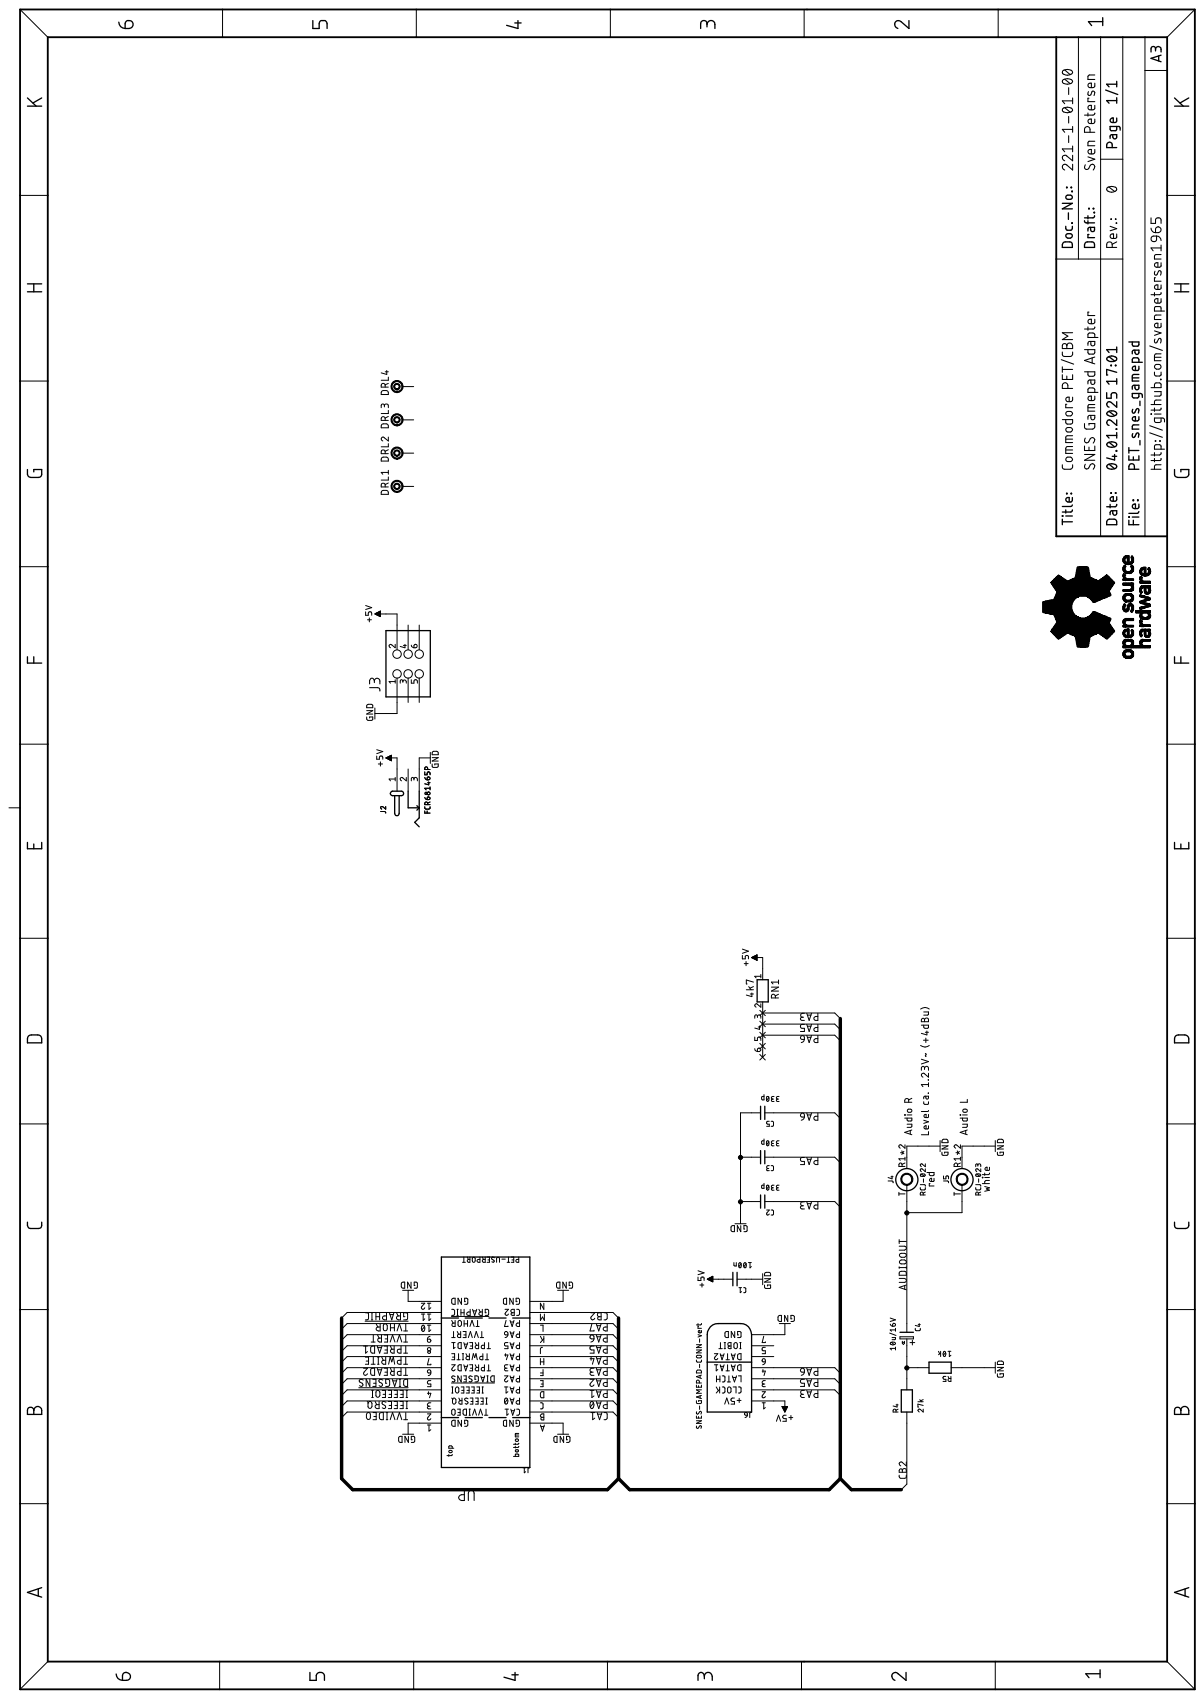
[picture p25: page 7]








PET_SNES_Test.docx | | 05.07.2026 16:53
Drafted by Sven Petersen | Page 1 of 5 | Doc.-No.: 221-6-02-00

### SNES Gamepad Adapter for Commodore PET Rev.0

### Testing

## Test Setup

- PET SNES Gamepad Adapter Rev. 0
- Diagnostic Cassette Port Dongle & 6-way ribbon cable
- A SNES Gamepad (non USB version)
- Commodore CBM3016
- Commodore CBM8032
- Commodore C64
- Software “SNES TEST.BAS.PRG” from zimmers.net (in snes_adapter.zip, see module description
- Software “PETROBOTS12.D64” (PETSCII Robots paid version from The 8bit-Guy) (https://www.the8bitguy.com/product-category/games/)

The PET SNES Gamepad Adapter was connected to the user port of the respective computer. The Gamepad was connected to the device under test.

Figure 1: The PET SNES Gamepad Adapter, powered by cassette port and an SD2PET Future with the required software

## Test Execution

### Testing The Readout of The Gamepad

The computer is the CBM3016, the software is SNES TEST.BAS.PRG. The program was stored on the SD2PET SD card. Loaded and started.

Every button was pressed on the gamepad. The software has display each of that properly.


PET_SNES_Test.docx | | 05.07.2026 16:53
Drafted by Sven Petersen | Page 2 of 5 | Doc.-No.: 221-6-02-00

Figure 2: SNEST TEST.BAS.PRG on CBM3016

The same test was conducted on the CBM8032. Again, every button was displayed properly.

Figure 3: SNEST TEST.BAS.PRG on CBM8032


PET_SNES_Test.docx | | 05.07.2026 16:53
Drafted by Sven Petersen | Page 3 of 5 | Doc.-No.: 221-6-02-00

### PETSCII Robots on CBM8032

Due to memory size, the PETSCII Robots software was run on the CBM8032, which had to be set to 40 columns previously.

As a game controller, the SNES Gamepad was selected.

Figure 4: PETSCII Robots on the CBM8032

The software reacted properly to the SNES Gamepad.

### PETSCII Robots on C64

The Gamepad was connected to the C64 via the device under test. A cassette dongle was required to power the gamepad. The software was run from the disk image “C64Robots v1.3.d64”, which was part of the PETSCII Robots purchase.


PET_SNES_Test.docx | | 05.07.2026 16:53
Drafted by Sven Petersen | Page 4 of 5 | Doc.-No.: 221-6-02-00

Figure 5: The PET SNES Gamepad Adapter Rev. 0 connected to the C64

Figure 6: PETSCII Robots on the C64

The software reacted properly to the SNES Gamepad.

Pos. Qty Value Footprint Ref.-No. Comment

1 1 221-2-01-00 2 Layer _PCB Rev. 0 2 layer, Cu 35µ, HASL, 71.0mm x 43.0mm, 1.6mm FR4

2 1 100n C-2,5 C1 ceramic capacitor, pitch: 2.5mm

3 3 330p C-2,5 C2, C3, C5 ceramic capacitor, pitch: 2.5mm

4 1 10u/16V C5,0/2,0 C4 aluminum electrolytic, ∅5.0mm/pitch 2.0mm 105°C,

l=11mm, e.G. Reichelt RD1C106M05011180 . Lay flat on

board.

5 1 Edge connector, 2x12,

3.96mm

USERPORT J1 edge connector, C64 user port, Ali Express, "series 805" or

other

6 1 FCR681465P FCR681465P J2 Cliff. 2,5mm/5.5mm barrel connector. E.g. Reichelt CLIFF

FCR681465P

7 1 2x3 box header, 2.54mm 2X03WV J3 e.g. Reichelt WSL 6G.

8 1 RCJ-022 RCJ-02X J4 CUI Inc., RCA jack, vertical, red. Mouser: 490-RCJ-022,
Digikey: CP-1407-ND. Alternative part: Keystone 577

9 1 RCJ-023 RCJ-02X J5 CUI Inc., RCA jack, vertical, white. Mouser: 490-RCJ-023,
Digikey: CP-1408-ND. Alternative part: Keystone 584

10 1 SNES-GAMEPAD-CONN-

# vert SNES_GAMEPAD _VERT J6 Vertical SNES Gamepad Connector from Ali Express

11 1 27k R-10 R4 1/4W, 1% or better

12 1 10k R-10 R5 1/4W, 1% or better

13 1 5x4k7 RN-6 RN1 Resistor network 4 pin, 5 resistors

## PET SNES Gamepad Adapter Rev. 0

## Bill of Material Rev. 0.0

PET_SNES_BOM_v0_0.xlsx

Drafted by Sven Petersen Page 1 of 1

08.07.2026 15:58
Doc.No.: 221-5-01-00.0

PET_SNES_Test.docx | | 05.07.2026 16:53
Drafted by Sven Petersen | Page 5 of 5 | Doc.-No.: 221-6-02-00

## Conclusion

The PET SNES Gamepad Adapter Rev. 0 is working properly.

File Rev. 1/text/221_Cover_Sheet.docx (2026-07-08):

Project Documentation

PET SNES Gamepad Adapter

Project number: 221

Revision: 1

Date: 10.05.2026


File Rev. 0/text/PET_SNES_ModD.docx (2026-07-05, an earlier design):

SNES Gamepad Adapter for Commodore PET Rev.0

Module Description

# Introduction

The SNES Gamepad Adapter for PET works with the respective games found on Bo Zimmerman’s website zimmers.net and PETSCII robots by the 8bit guy.

The source of information about the hardware requirements is the file snes_adapter.zip from zimmers.net (https://www.zimmers.net/anonftp/pub/cbm/documents/projects/interfaces/index.html). A further source was https://wiki.superfamicom.org/schematics-ports-and-pinouts#. The zimmers.net file contains references to texelex.com and Steve Lewis plus source code in C and BASIC for polling the gamepad.


Figure 1: PET SNES Gamepad Adapter Rev. 0 (Dimensions)

Since the PET User Port does not provide +5V supply voltage, there is a 6 was box pin header form connecting a cassette port dongle (https://github.com/svenpetersen1965/C64-Diagnostic-Rev.-586220-Harness/tree/master/Diag586220_Harness/Diag586220_Cassette_Port) (where +5V can be tapped for the Gamepad. This is the recommended solution. Further, there is a 5.5mm/2.1mm barrel connector for a +5V external PSU.

The CB2 audio is tapped from the user port and connected to two RCA jacks via a voltage divider and a capacitor for connecting external PC speakers.

The adapter works with PETSCII Robots for the C64, as well. Since the 5V of the C64 are not connected (that would be the TVVIDEO pin of the user port), either a Cassette Port Dongle or an external Power Supply is required.


Figure 2: Backside of a CBM8032 - SNES Adapter with Cassette Port Dongle (and SD2PET Future)

# Pinouts

## J1- User Port

2x12 Edge Connector, 3.96mm pitch

Pin | Signal | Gamepad
1, 12, A, N | GND | GND
F | PA3 | Clock
J | PA5 | Latch
K | PA6 | Data

## J2 – Power Supply Connector

5,5mm/2,5mm barrel connector (Cliff FCR681465P)

Pin | Signal
Center | +5VDC
Shaft | GND

This is an alternative power connector, which can be used with an external +5V power supply. It is not the preferred way of powering the module.

## J3 - Power connector (from cassette port)

2x3 pin box connector

Signal | Pin | Pin | Signal
GND | 1 | 2 | +5V
- | 3 | 4 | -
- | 5 | 6 | -

Powering from cassette port is the preferred way, since it switches off together with the PET. This requires a Cassette Port Dongle (see C64 Diagnostic harness (https://github.com/svenpetersen1965/C64-Diagnostic-Rev.-586220-Harness)).

## J4, J5 – Audio RCA jacks

2 vertical RCA jacks

Connector | Color | Center | Ring | Type
J4 | Red | Audio | GND | CUI Inc. RCJ-022
J5 | White | Audio | GND | CUI Inc. RCJ-023

Note: The CUI Inc connectors are pretty wide spread and available from Mouser and Digikey etc. There are acceptable and cheaper connectors from AliExpress, which perfectly fit into the footprint. Click URL (https://de.aliexpress.com/item/1005004200016377.html)

Both connectors are connected to the same source. The audio level is about 1.23V~ (+4dBu).

## J6 – SNES Gamepad

SNES Gamepad Connector (vertical)


Figure 3: SNES Gamepad Connector

Pin | Signal
1 | +5V
2 | Clock
3 | Latch
4 | Data1
5 | Data2 (not connected)
6 | IOBIT (not connected)
7 | GND

# Case

There is a 3D printed case and a case label for this project.


Figure 4: PET SNES Gamepad Adapter (in case)

# Programming Hints

First, the data direction register of the user port needs to be set correctly. Clock (bit #3) and Latch (bit#5) are outputs of the user port, Data (bit#6) is an input:

POKE 59459,8+32

While scanning the gamepad, a (positive) latch pulse is required first:

POKE59457,32:POKE59457,0:REM LATCH PULSE

The gamepad outputs a 12 bit word, MSB first. After the latch pulse, the MSB is present at the data input (bit#6) of the user port.

GW=0:B=2048
FOR I=12 TO 1 STEP-1
IF PEEK(59457) AND 64 THEN GW=GW+B:REM IS BIT#6 SET?
B=B/2
POKE59457,8:POKE59457,0:REM PULSE CLOCK
NEXT I

An active data bit is LOW, this is, why it needs to be inverted

GW=4096 + NOT GW:REM INVERT GW

Now, the gamepad word can be decoded:

Bit | Bit Value | Gamepad
0 | 1 | Fire-R
1 | 2 | Fire-L
2 | 4 | X
3 | 8 | A
4 | 16 | Right
5 | 32 | Left
6 | 64 | Down
7 | 128 | Up
8 | 256 | Start
9 | 512 | Select
10 | 1024 | Y
11 | 2048 | B

The source is SNES TEST.BAS.PRG from the previously mentioned file snes_adapter.zip

# Revision History

## Rev. 0

Prototype, tested ok

PET_SNES_ModD.docx 05.07.2026 16:54 Drafted by Sven Petersen Page 2 of 2 Doc.-No.: 221-6-01-00

PET_SNES_ModD.docx 05.07.2026 16:54 Drafted by Sven Petersen Page 1 of 1 Doc.-No.: 221-6-01-00

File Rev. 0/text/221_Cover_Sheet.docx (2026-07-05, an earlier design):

Project Documentation

PET SNES Gamepad Adapter

Project number: 221

Revision: 0

Date: 04.01.2025


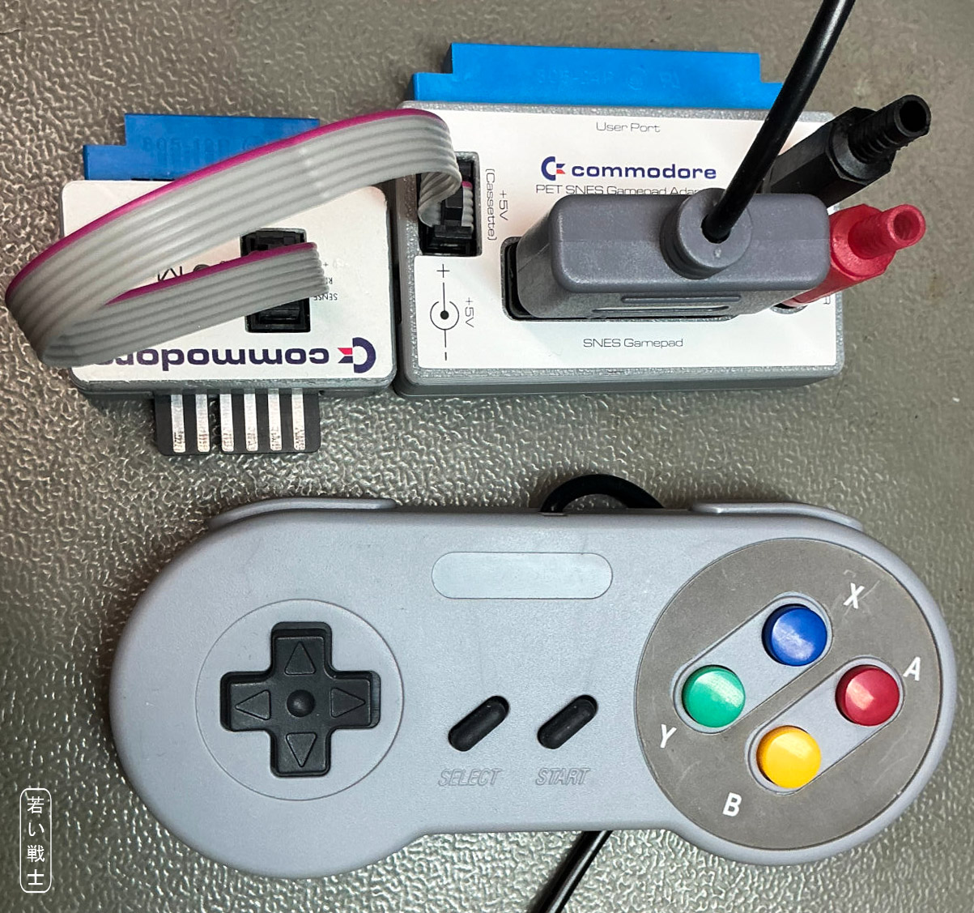
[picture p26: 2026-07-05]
Rev. 0/pictures/0708_-_SNES_Gamepad_Adapter_v0.JPG

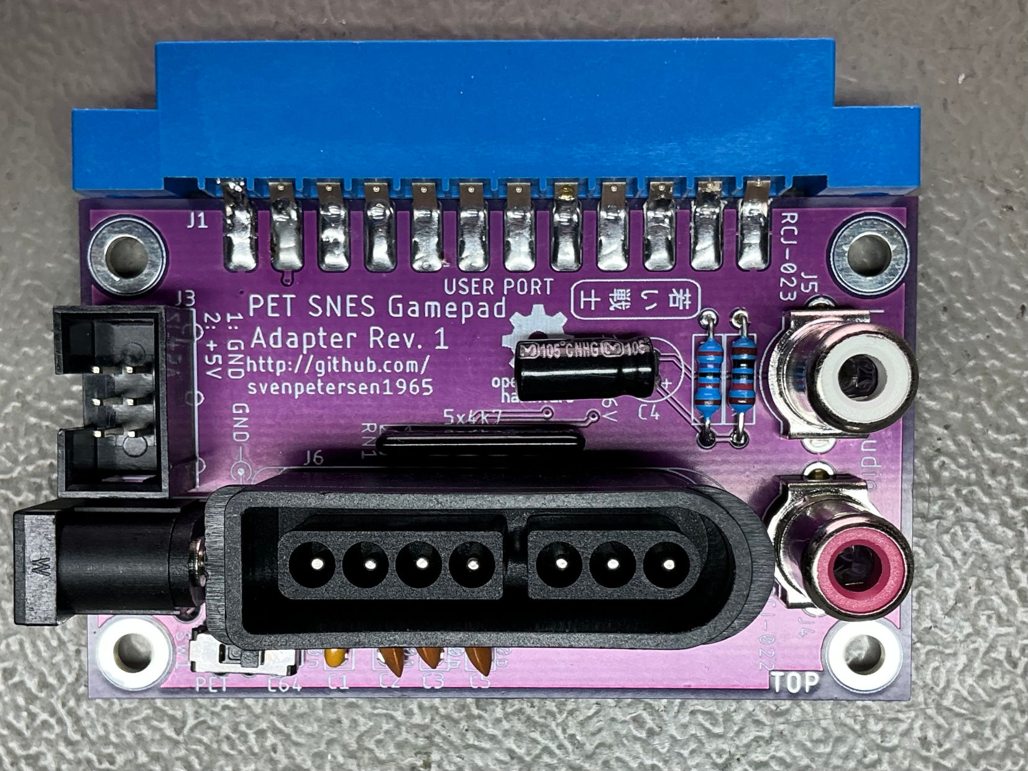
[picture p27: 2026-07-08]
Rev. 1/pictures/3979_-_SNES_Gamepad_Adapter_v1_PCB.JPG

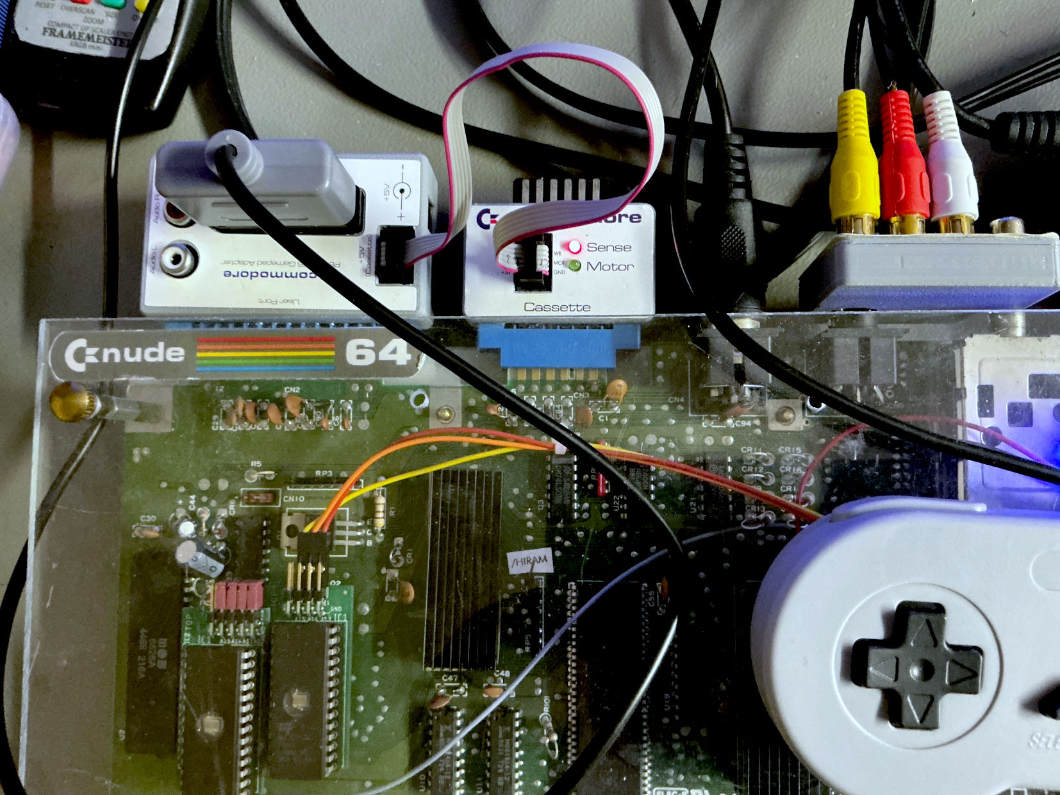
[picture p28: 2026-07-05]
Rev. 0/pictures/3185_-_PET_SNES_GP_C64.JPG

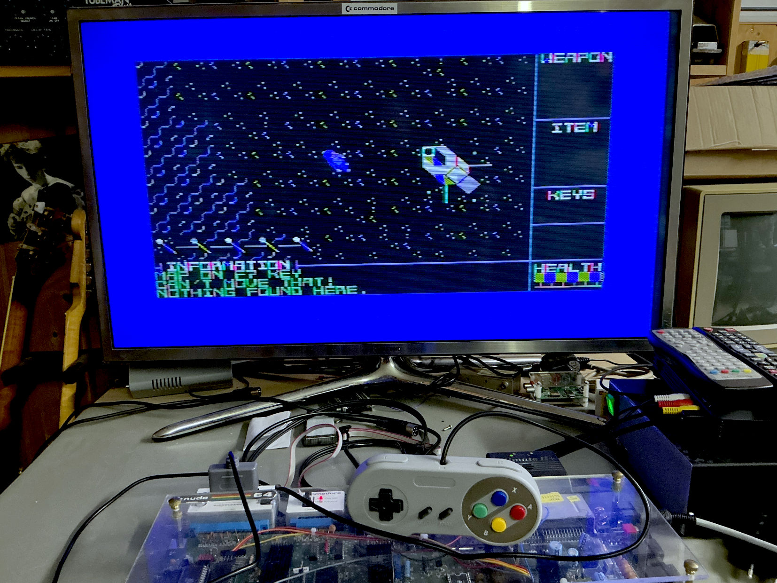
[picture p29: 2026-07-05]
Rev. 0/pictures/3187_PETSCII_Robots_C64.JPG

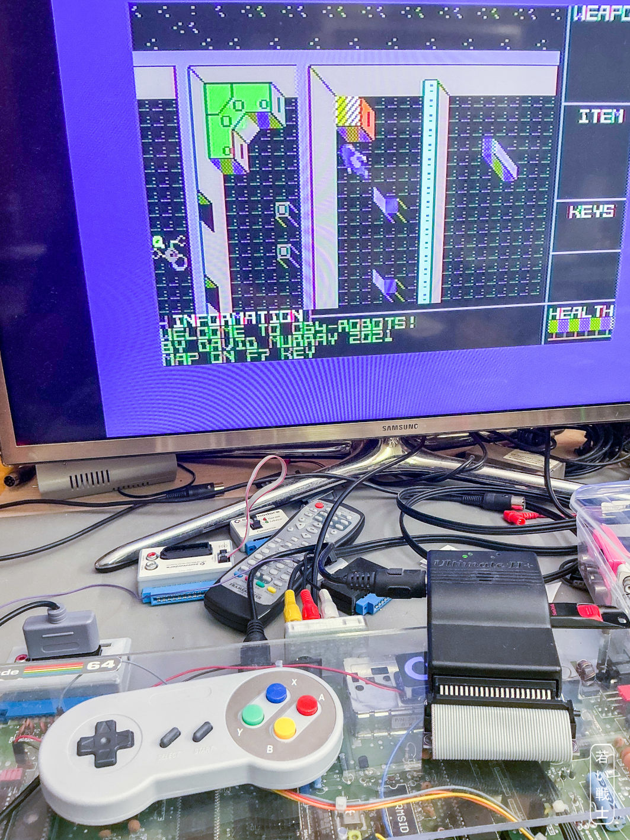
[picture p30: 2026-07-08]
Rev. 1/pictures/4252_-_PETSCII_Robots_C64.JPG

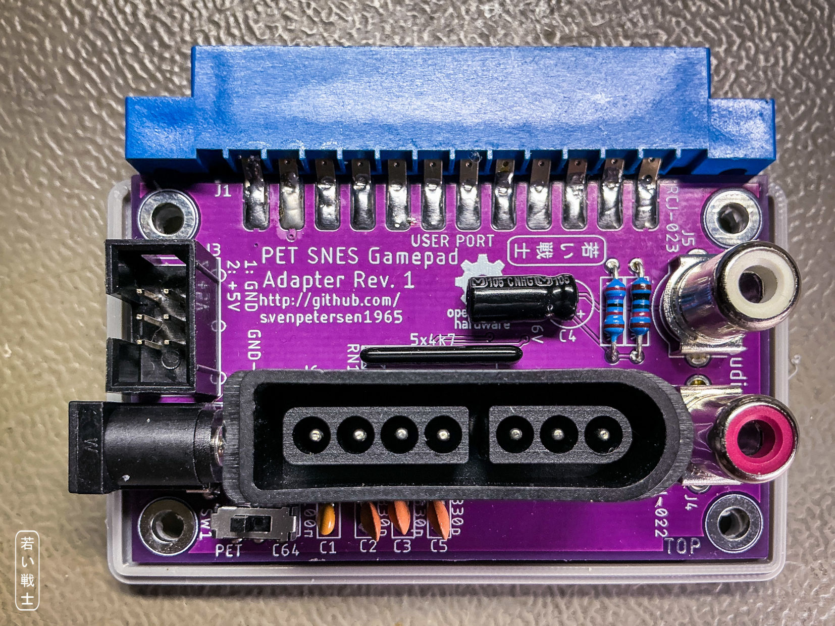
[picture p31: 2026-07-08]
Rev. 1/pictures/4299_-_SNES_Gamepad_Adapter_v1_PCB.JPG

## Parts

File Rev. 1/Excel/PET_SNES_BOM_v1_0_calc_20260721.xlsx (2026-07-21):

PET SNES Gamepad Adapter Rev. 1
BOM Value of 21.07.2026
Pos. | Qty | Value | each | total | Comment
1 | 1 | 221-2-01-00 | 2.00 € | 2.00 € | 2 layer, Cu 35µ, HASL, 71.0mm x 43.0mm, 1.6mm FR4
2 | 1 | 100n | 0.05 € | 0.05 € | ceramic capacitor, pitch: 2.5mm
3 | 3 | 330p | 0.05 € | 0.15 € | ceramic capacitor, pitch: 2.5mm
4 | 1 | 10u/16V | 0.05 € | 0.05 € | aluminum electrolytic, Æ5.0mm/pitch 2.0mm 105°C, l=11mm, e.G. Reichelt RD1C106M05011180 . Lay flat on board.
5 | 1 | Edge connector, 2x12, 3.96mm | 6.00 € | 6.00 € | edge connector, C64 user port, Ali Express, "series 805" or other
6 | 1 | FCR681465P | 1.70 € | 1.70 € | Cliff. 2,5mm/5.5mm barrel connector. E.g. Reichelt CLIFF FCR681465P
7 | 1 | 2x3 box header, 2.54mm | 0.18 € | 0.18 € | e.g. Reichelt WSL 6G.
8 | 1 | RCJ-022 | 1.09 € | 1.09 € | CUI Inc., RCA jack, vertical, red. Mouser: 490-RCJ-022, Digikey: CP-1407-ND. Alternative part: Keystone 577
9 | 1 | RCJ-023 | 1.14 € | 1.14 € | CUI Inc., RCA jack, vertical, white. Mouser: 490-RCJ-023, Digikey: CP-1408-ND. Alternative part: Keystone 584
10 | 1 | SNES-GAMEPAD-CONN-vert | 2.29 € | 2.29 € | Vertical SNES Gamepad Connector from Ali Express (https://de.aliexpress.com/item/1005009348316606.html)
11 | 1 | 27k | 0.05 € | 0.05 € | 1/4W, 1% or better
12 | 1 | 10k | 0.05 € | 0.05 € | 1/4W, 1% or better
13 | 1 | 5x4k7 | 0.10 € | 0.10 € | Resistor network 4 pin, 5 resistors
14 | 1 | mini slide switch, 2.54mm, DPDT, through hole | 0.10 € | 0.10 €
15 |  | Total |  | 14.95 €

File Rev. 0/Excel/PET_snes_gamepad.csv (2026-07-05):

Qty | Value | Device | Package | Parts | Description
1 |  | 2X03WV | 2X03WV | J3
4 |  | BOHR3,5 | BOHR3,5 | DRL1, DRL2, DRL3, DRL4
1 | 100n | CAP01 | C-2,5 | C1
1 | 10k | RES04 | R-10 | R5
1 | 10u/16V | C05,0/2,0 | C5,0/2,0 | C4
1 | 27k | RES04 | R-10 | R4
3 | 330p | CAP01 | C-2,5 | C2, C3, C5
1 | 5x4k7 | RN05 | RN-6 | RN1
1 | FCR681465P | FCR681465P | FCR681465P | J2
1 | OPEN_SOURCE_HW | OPEN_SOURCE_HW | OPENHW | U$2
1 | PET-USERPORT | PET-USERPORT | USERPORT | J1
1 | RCJ-022 | RCJ-02X | RCJ-02X | J4
1 | RCJ-023 | RCJ-02X | RCJ-02X | J5
1 | SNES-GAMEPAD-CONN-vert | GAMEPAD-CONN_SNESCONN | SNES_GAMEPAD_VERT | J6

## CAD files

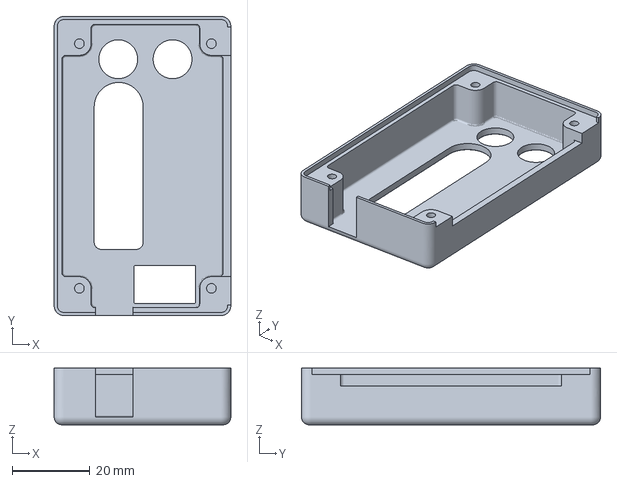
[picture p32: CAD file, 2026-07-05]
Case/Rev. 0/gcode/PET_SNES_top_shell_20250406.3mf
45.5 x 77.0 x 14.6 mm

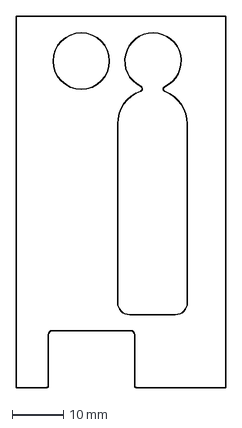
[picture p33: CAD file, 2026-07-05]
Case/Rev. 0/Label/outline.dxf
40.9 x 72.4 mm

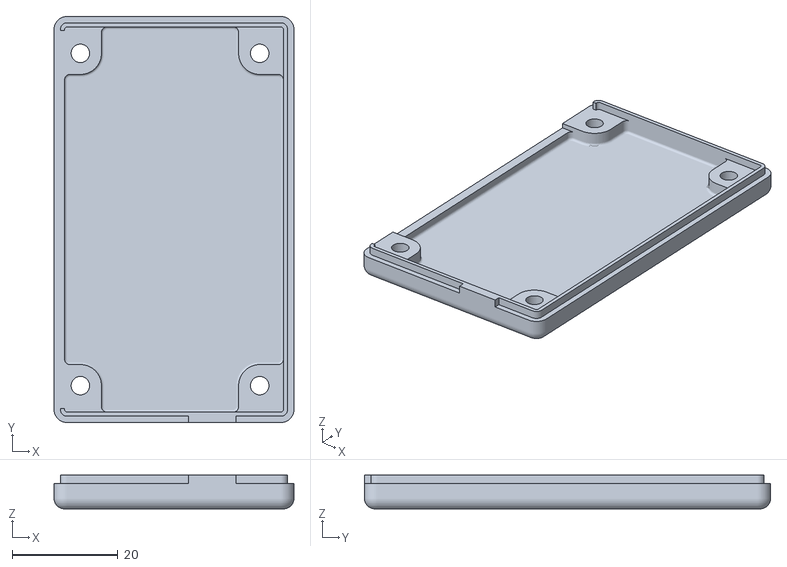
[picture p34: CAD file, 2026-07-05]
Case/Rev. 0/stl/bottom_shell.stl
45.5 x 77.0 x 6.40

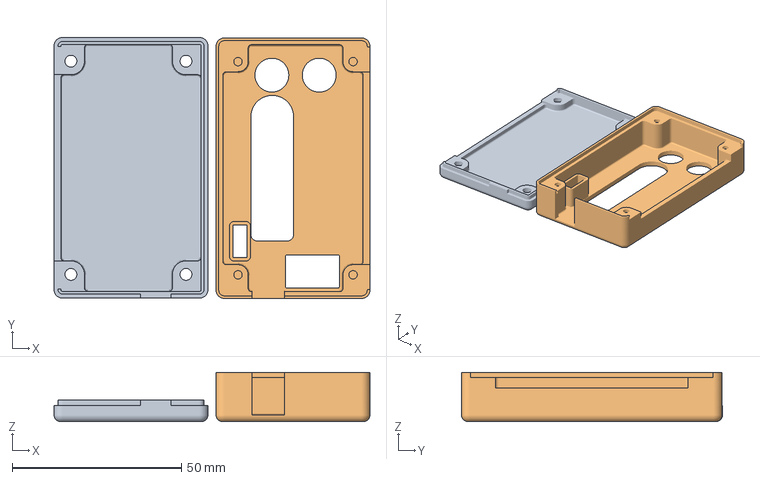
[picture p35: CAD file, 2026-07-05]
Case/Rev. 1/gcode/PETSNES_both_shell.3mf
93.4 x 77.1 x 14.6 mm
PETSNES_bottom_shell.stl
PETSNES_top_shell.stl

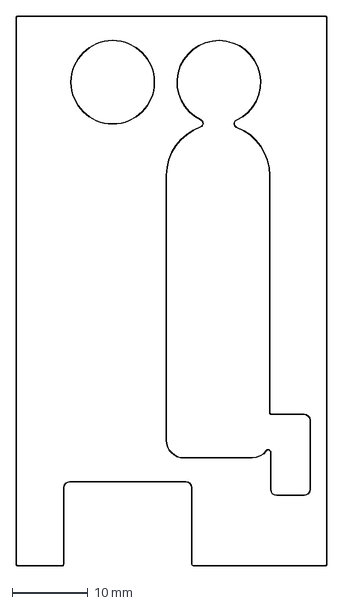
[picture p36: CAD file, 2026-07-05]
Case/Rev. 1/label/label_outline.dxf
40.9 x 72.4 mm

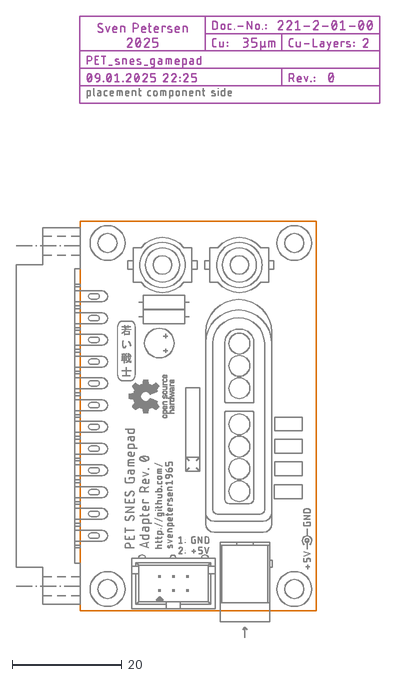
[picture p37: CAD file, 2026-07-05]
Rev. 0/dxf/PET_snes_gamepad.dxf
66.1 x 113.2

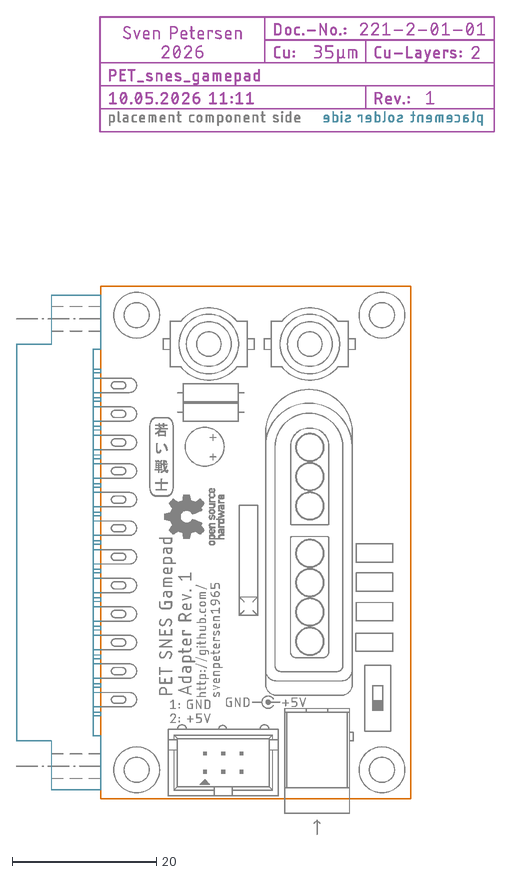
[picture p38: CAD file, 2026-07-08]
Rev. 1/dxf/PET_snes_gamepad.dxf
66.3 x 113.4

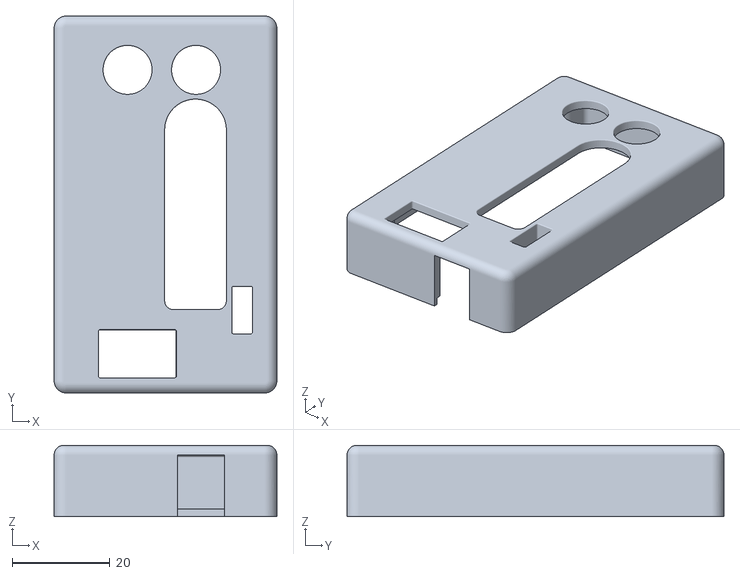
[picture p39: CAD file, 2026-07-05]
Case/Rev. 1/stl/PETSNES_top_shell.stl
45.5 x 77.0 x 14.6

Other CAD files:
Case/Rev. 1/stl/PETSNES_bottom_shell.stl
Case/Rev. 0/stl/top_shell.stl
Case/Rev. 0/fusion360/PET_SNES_Gamepad_Adapter_v0.f3d
Case/Rev. 1/fusion360/PET_SNES_Gamepad_Adapter_v1.f3d

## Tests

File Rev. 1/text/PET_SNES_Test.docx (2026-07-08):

SNES Gamepad Adapter for Commodore PET Rev.1

Testing

# Test Setup

- PET SNES Gamepad Adapter Rev. 1
- Diagnostic Cassette Port Dongle & 6-way ribbon cable
- A SNES Gamepad (non USB version)
- Commodore CBM3016
- Commodore CBM8032
- Commodore C64
- Software “SNES TEST.BAS.PRG” from zimmers.net (in snes_adapter.zip, see module description
- Software “PETROBOTS12.D64” (PETSCII Robots paid version from The 8bit-Guy (https://www.the8bitguy.com/product-category/games/))

The PET SNES Gamepad Adapter was connected to the user port of the respective computer. The Gamepad was connected to the device under test.


Figure 1: The PET SNES Gamepad Adapter, powered by cassette port and an SD2PET Future with the required software

# Test Execution

## Testing The Readout of The Gamepad

The computer is the CBM8032, the software is SNES TEST.BAS.PRG. The program was stored on the SD2PET SD card. Loaded and started.

Every button was pressed on the gamepad. The software has display each of that properly.

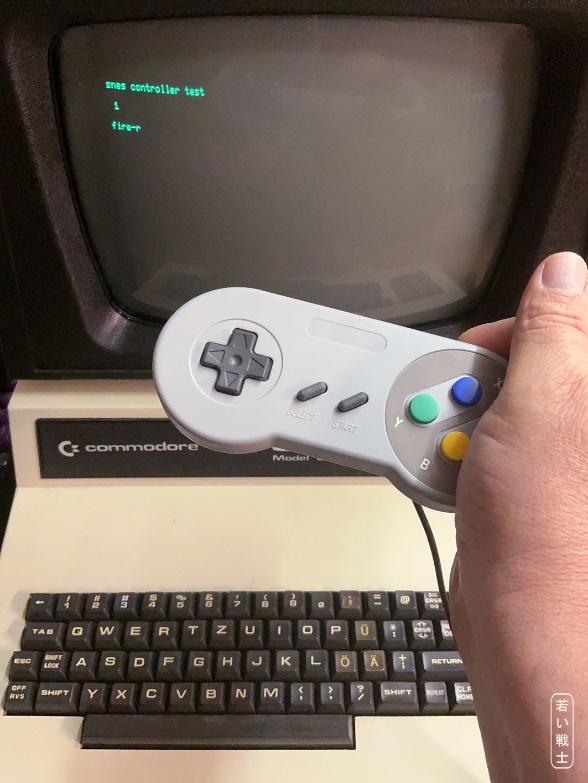
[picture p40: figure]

Figure 2: SNEST TEST.BAS.PRG on CB8032

## PETSCII Robots on CBM8032

Due to memory size, the PETSCII Robots software was run on the CBM8032, which had to be set to 40 columns previously.

As a game controller, the SNES Gamepad was selected.

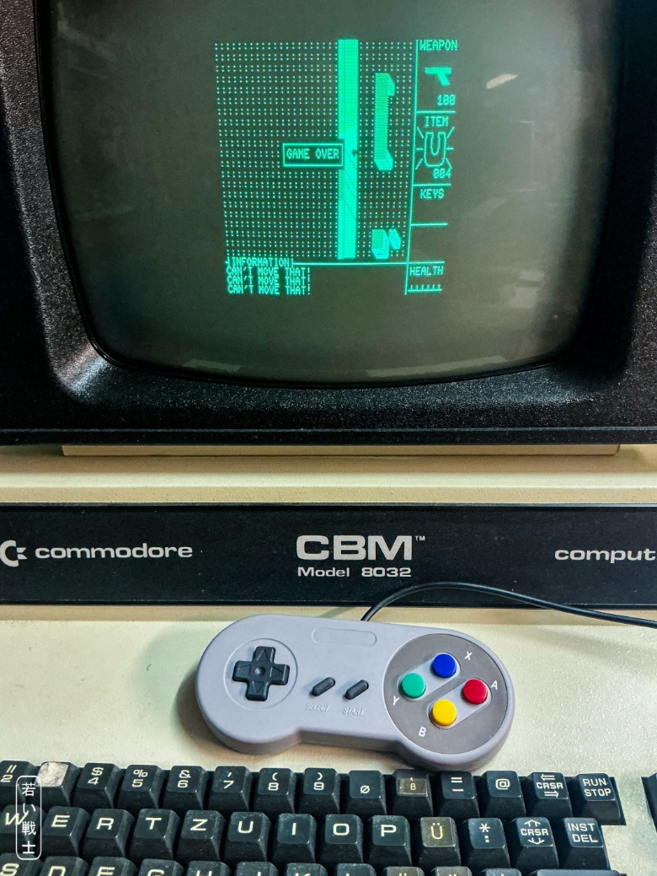
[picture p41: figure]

Figure 3: PETSCII Robots on the CBM8032

The software reacted properly to the SNES Gamepad.

## PETSCII Robots on C64

The Gamepad was connected to the C64 via the device under test. A cassette dongle was required to power the gamepad. The software was run from the disk image “C64Robots v1.3.d64”, which was part of the PETSCII Robots purchase.

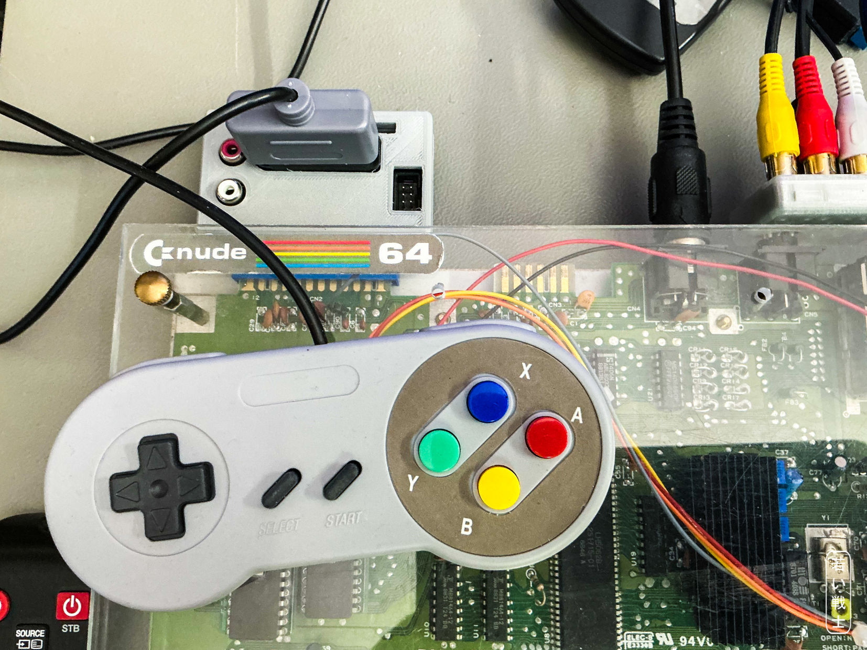
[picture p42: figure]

Figure 4: The PET SNES Gamepad Adapter Rev. 0 connected to the C64

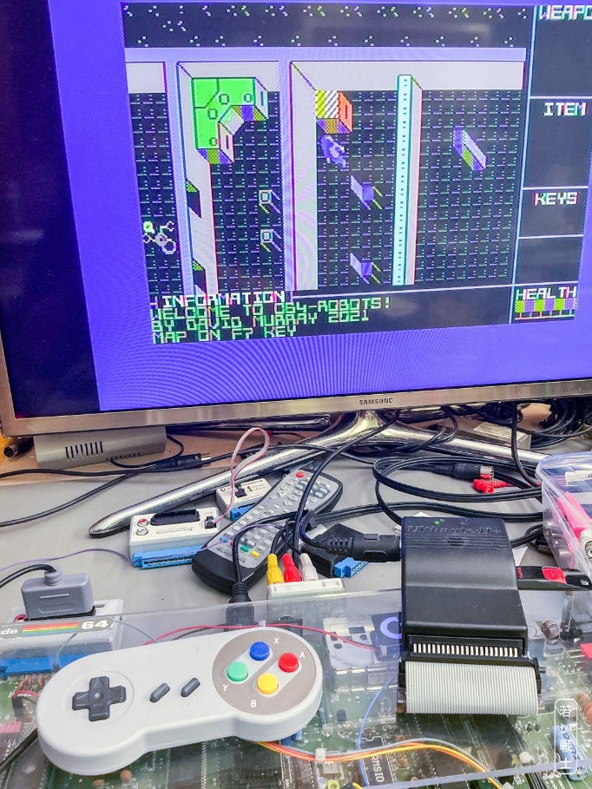
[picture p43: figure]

Figure 5: PETSCII Robots on the C64

The software reacted properly to the SNES Gamepad.

# Conclusion

The PET SNES Gamepad Adapter Rev. 1 is working properly.

PET_SNES_Test.docx 08.07.2026 15:50 Drafted by Sven Petersen Page 2 of 2 Doc.-No.: 221-6-02-01

PET_SNES_Test.docx 08.07.2026 15:50 Drafted by Sven Petersen Page 1 of 1 Doc.-No.: 221-6-02-01

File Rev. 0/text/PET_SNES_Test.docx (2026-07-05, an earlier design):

SNES Gamepad Adapter for Commodore PET Rev.0

Testing

# Test Setup

- PET SNES Gamepad Adapter Rev. 0
- Diagnostic Cassette Port Dongle & 6-way ribbon cable
- A SNES Gamepad (non USB version)
- Commodore CBM3016
- Commodore CBM8032
- Commodore C64
- Software “SNES TEST.BAS.PRG” from zimmers.net (in snes_adapter.zip, see module description
- Software “PETROBOTS12.D64” (PETSCII Robots paid version from The 8bit-Guy (https://www.the8bitguy.com/product-category/games/))

The PET SNES Gamepad Adapter was connected to the user port of the respective computer. The Gamepad was connected to the device under test.

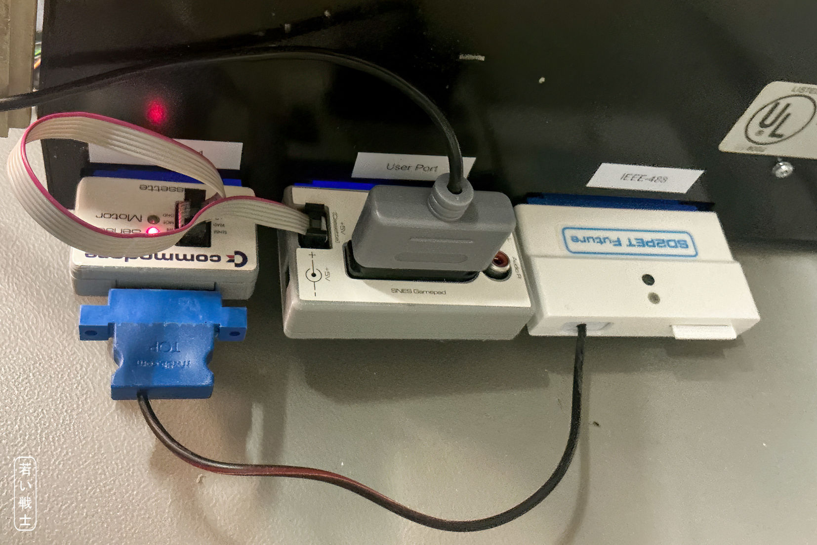
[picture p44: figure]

Figure 1: The PET SNES Gamepad Adapter, powered by cassette port and an SD2PET Future with the required software

# Test Execution

## Testing The Readout of The Gamepad

The computer is the CBM3016, the software is SNES TEST.BAS.PRG. The program was stored on the SD2PET SD card. Loaded and started.

Every button was pressed on the gamepad. The software has display each of that properly.

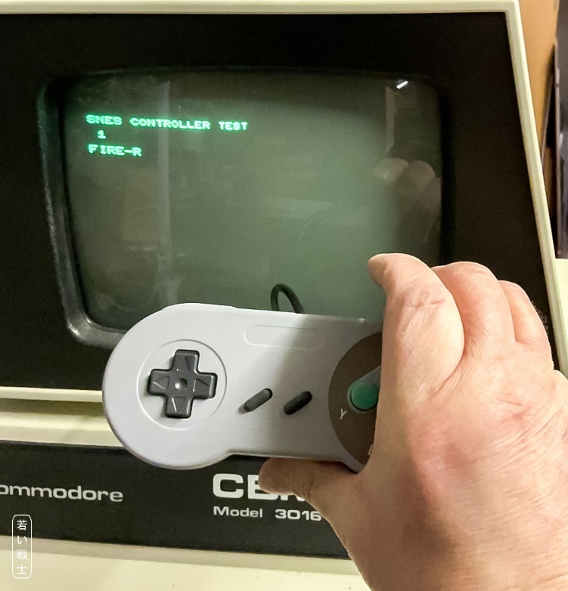
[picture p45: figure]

Figure 2: SNEST TEST.BAS.PRG on CBM3016

The same test was conducted on the CBM8032. Again, every button was displayed properly.

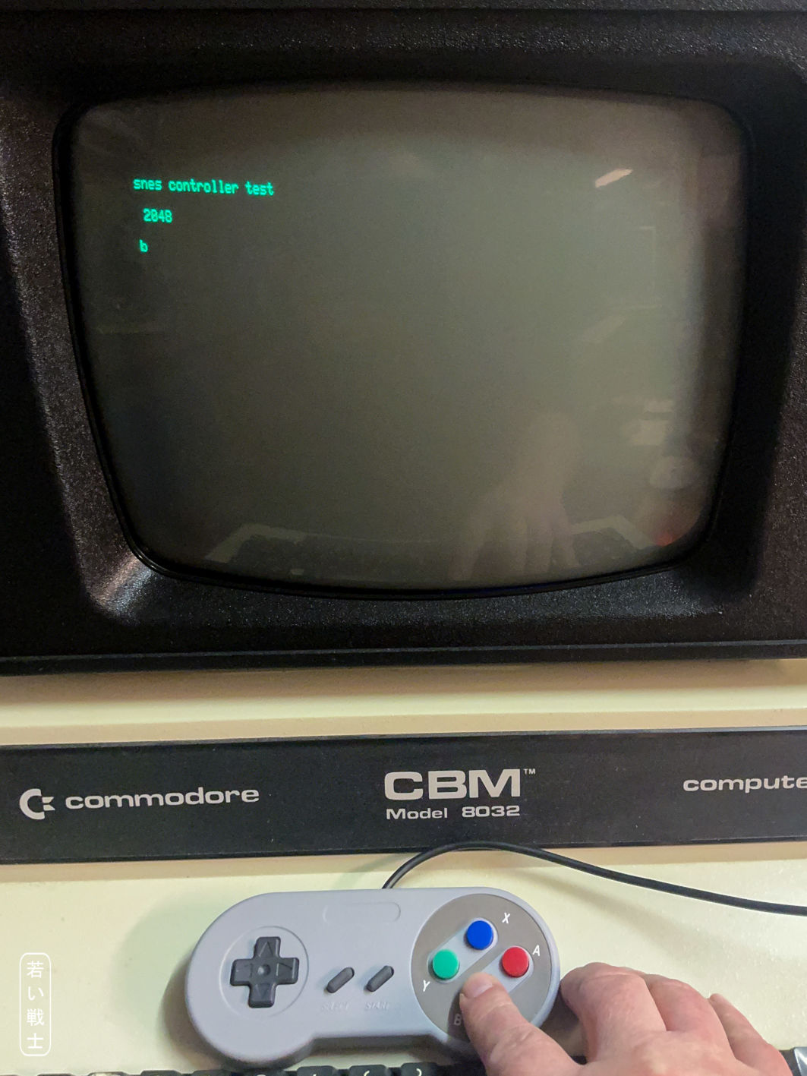
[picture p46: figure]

Figure 3: SNEST TEST.BAS.PRG on CBM8032

## PETSCII Robots on CBM8032

Due to memory size, the PETSCII Robots software was run on the CBM8032, which had to be set to 40 columns previously.

As a game controller, the SNES Gamepad was selected.


Figure 4: PETSCII Robots on the CBM8032

The software reacted properly to the SNES Gamepad.

## PETSCII Robots on C64

The Gamepad was connected to the C64 via the device under test. A cassette dongle was required to power the gamepad. The software was run from the disk image “C64Robots v1.3.d64”, which was part of the PETSCII Robots purchase.


Figure 5: The PET SNES Gamepad Adapter Rev. 0 connected to the C64

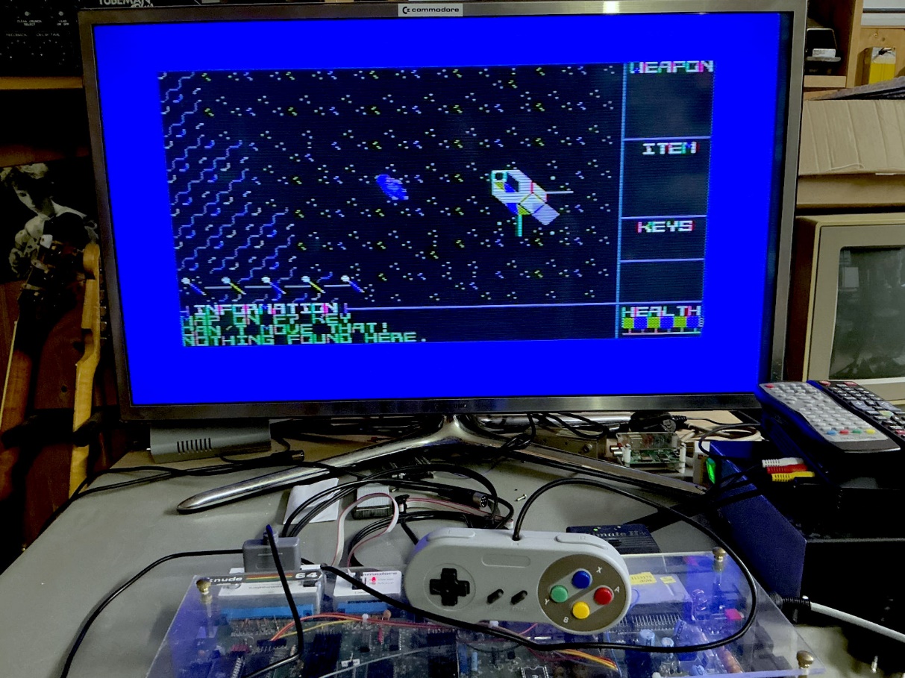
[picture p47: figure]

Figure 6: PETSCII Robots on the C64

The software reacted properly to the SNES Gamepad.

# Conclusion

The PET SNES Gamepad Adapter Rev. 0 is working properly.

PET_SNES_Test.docx 05.07.2026 16:53 Drafted by Sven Petersen Page 2 of 2 Doc.-No.: 221-6-02-00

PET_SNES_Test.docx 05.07.2026 16:53 Drafted by Sven Petersen Page 1 of 1 Doc.-No.: 221-6-02-00

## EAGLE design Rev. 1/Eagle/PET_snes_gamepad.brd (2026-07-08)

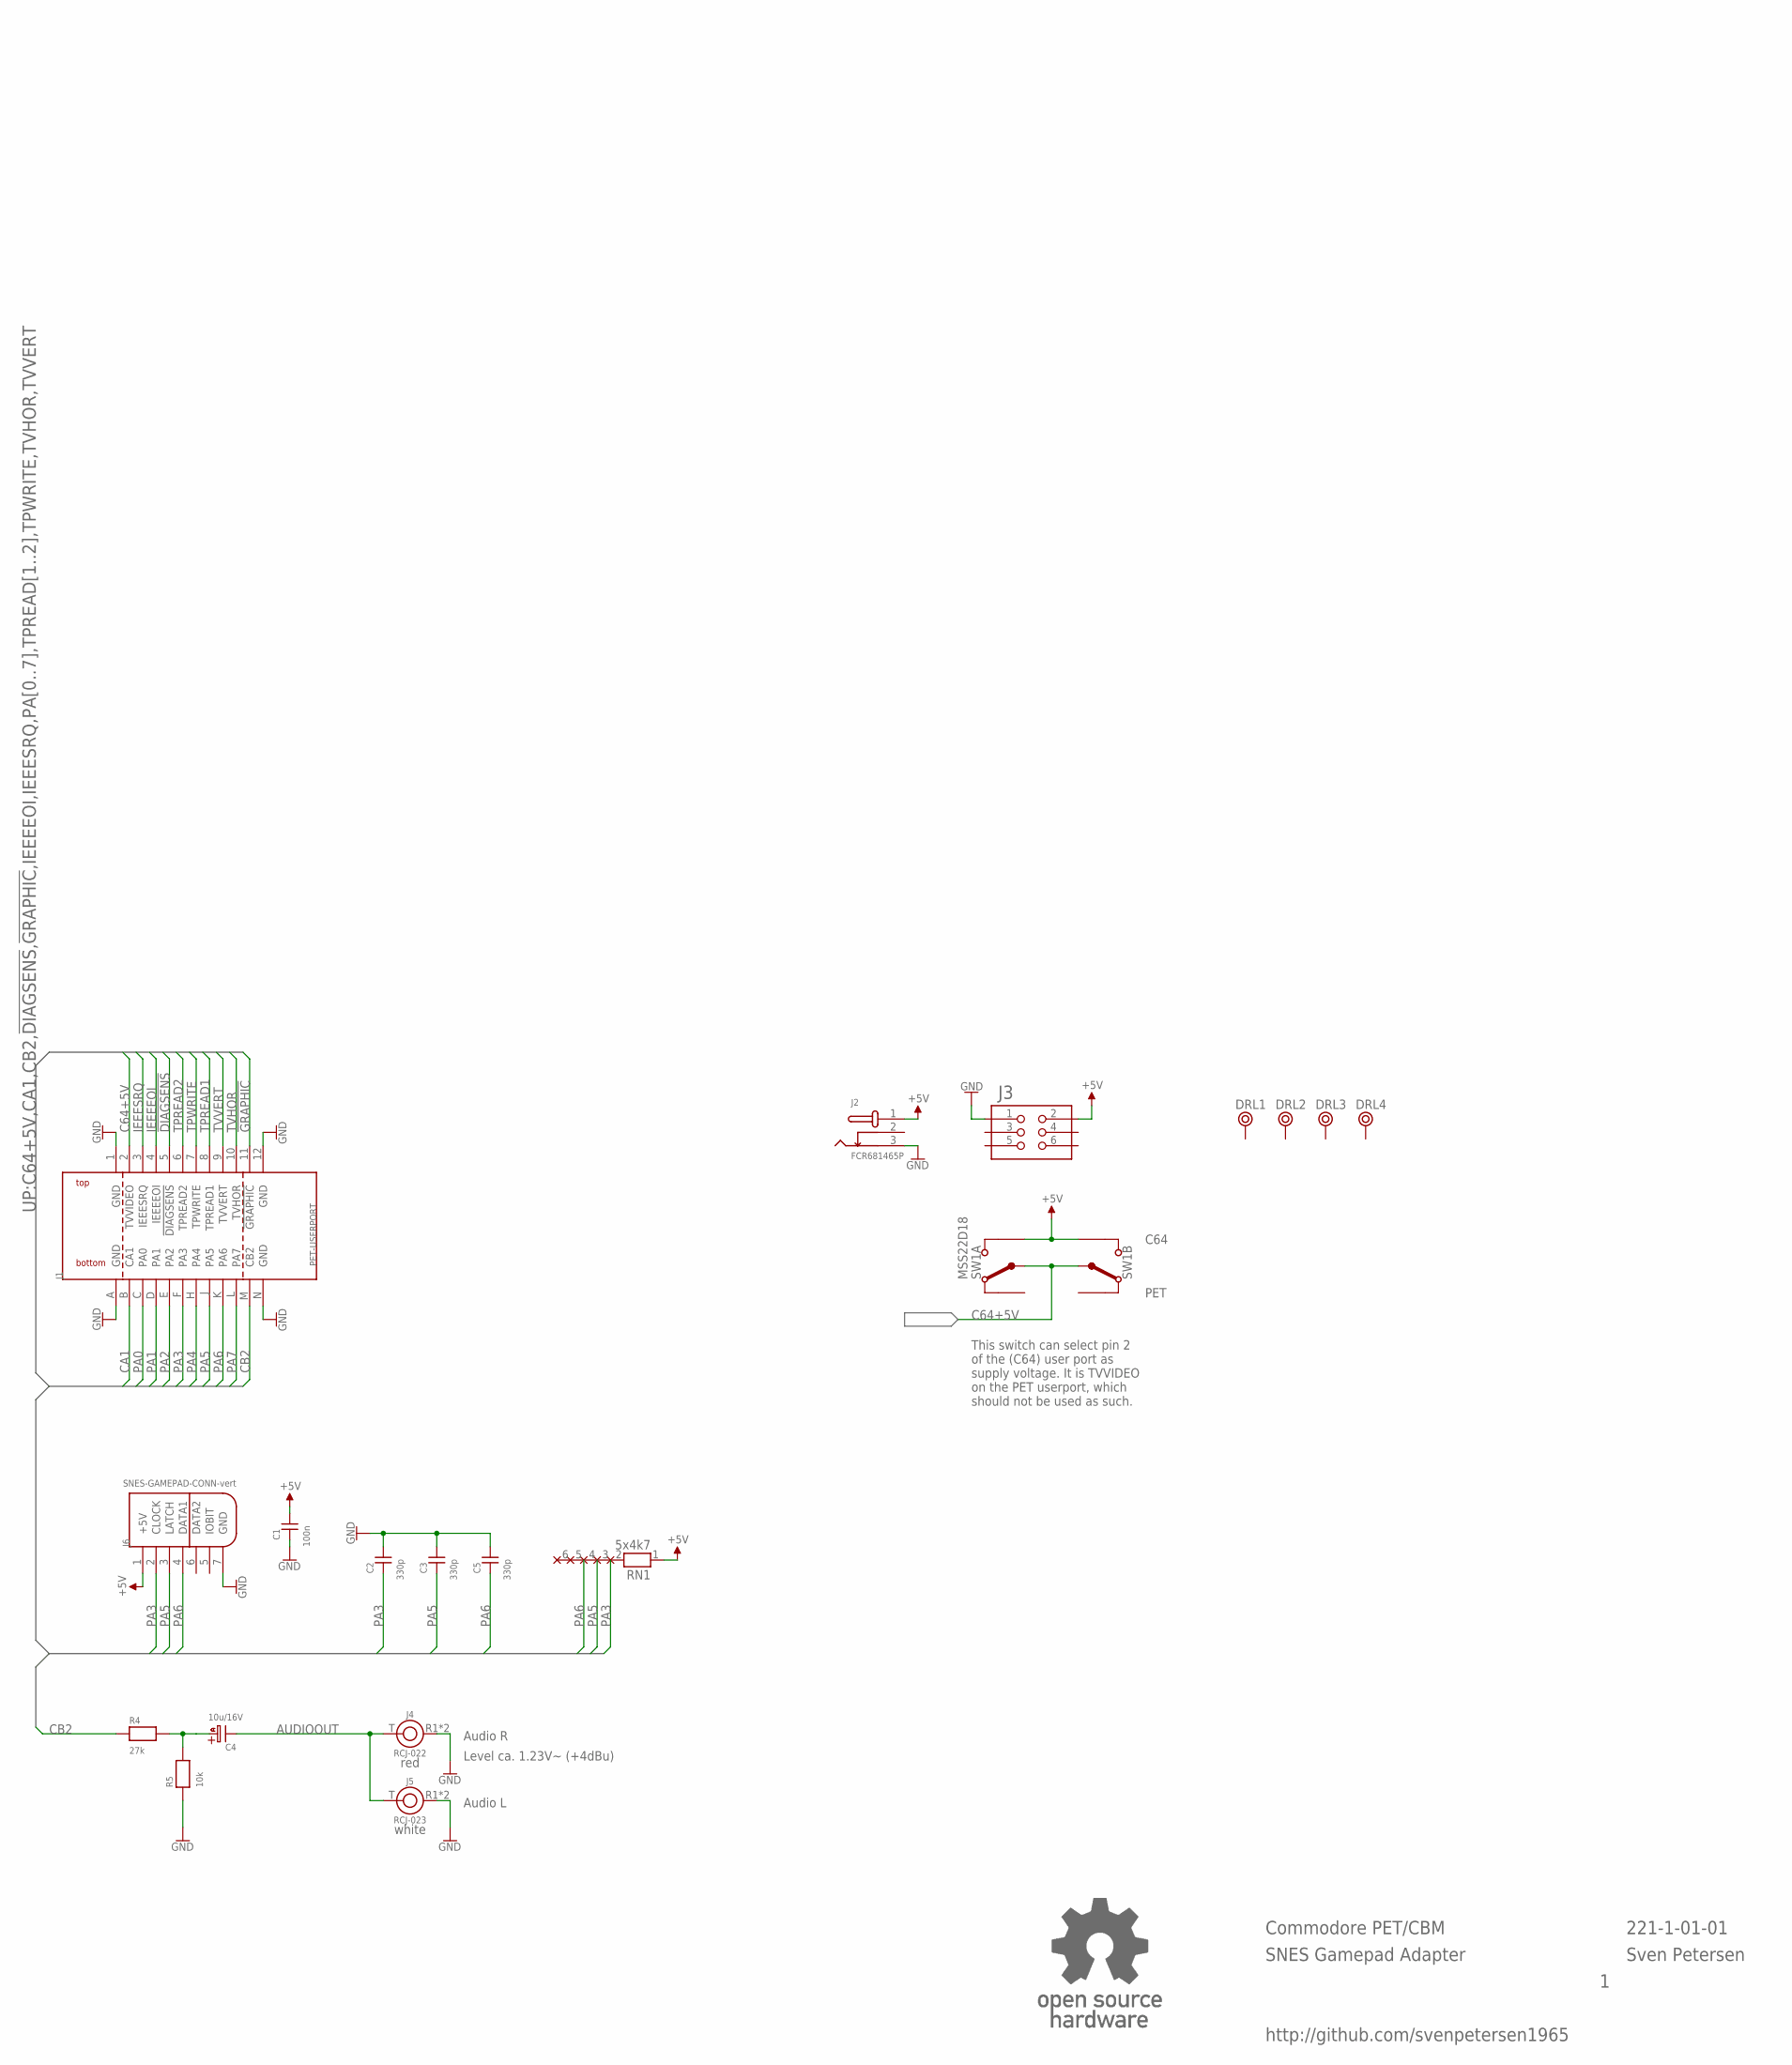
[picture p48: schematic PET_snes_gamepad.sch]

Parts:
C1: 100n; C-2,5
C2, C3, C5: 330p; C-2,5
C4: 10u/16V; C5,0/2,0
DRL1, DRL2, DRL3, DRL4: BOHR3,5
J1: PET-USERPORT; USERPORT
J2: FCR681465P
J3: 2X03WV
J4: RCJ-022; RCJ-02X
J5: RCJ-023; RCJ-02X
J6: SNES-GAMEPAD-CONN-vert; SNES_GAMEPAD_VERT
R4: 27k; R-10
R5: 10k; R-10
RN1: 5x4k7; RN-6
SW1: MSS22D18; DPDT_9MM
U$2: OPEN_SOURCE_HW; OPENHW

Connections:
!DIAGSENS: J1.5 (!DIAGSENS)
!GRAPHIC: J1.11 (!GRAPHIC)
+5V: C1.2, J2.1, J3.2, J6.1 (+5V), RN1.1, SW1.1 (UP), SW1.6 (UP)
AUDIOOUT: C4.K (-), J4.T, J5.T
C64+5V: J1.2 (TVVIDEO), SW1.2 (COM), SW1.5 (COM)
CA1: J1.B (CA1)
CB2: J1.M (CB2), R4.1
GND: C1.1, C2.2, C3.2, C5.2, J1.1 (GND), J1.12 (GND), J1.A (GND), J1.N (GND), J2.3, J3.1, J4.R1 (R), J4.R2 (R), J5.R1 (R), J5.R2 (R), J6.7 (GND), R5.1
IEEEEOI: J1.4 (IEEEEOI)
IEEESRQ: J1.3 (IEEESRQ)
unnamed: C4.A (+), R4.2, R5.2
PA0: J1.C (PA0)
PA1: J1.D (PA1)
PA2: J1.E (PA2)
PA3: C2.1, J1.F (PA3), J6.2 (CLOCK), RN1.2
PA4: J1.H (PA4)
PA5: C3.1, J1.J (PA5), J6.3 (LATCH), RN1.3
PA6: C5.1, J1.K (PA6), J6.4 (DATA1), RN1.4
PA7: J1.L (PA7)
TPREAD1: J1.8 (TPREAD1)
TPREAD2: J1.6 (TPREAD2)
TPWRITE: J1.7 (TPWRITE)
TVHOR: J1.10 (TVHOR)
TVVERT: J1.9 (TVVERT)

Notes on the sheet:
http://github.com/svenpetersen1965
Commodore PET/CBM
SNES Gamepad Adapter
Sven Petersen
221-1-01-01
red
white
Audio R
Audio L
Level ca. 1.23V~ (+4dBu)
PET
C64
This switch can select pin 2 of the (C64) user port as supply voltage. It is TVVIDEO on the PET userport, which should not be used as such.

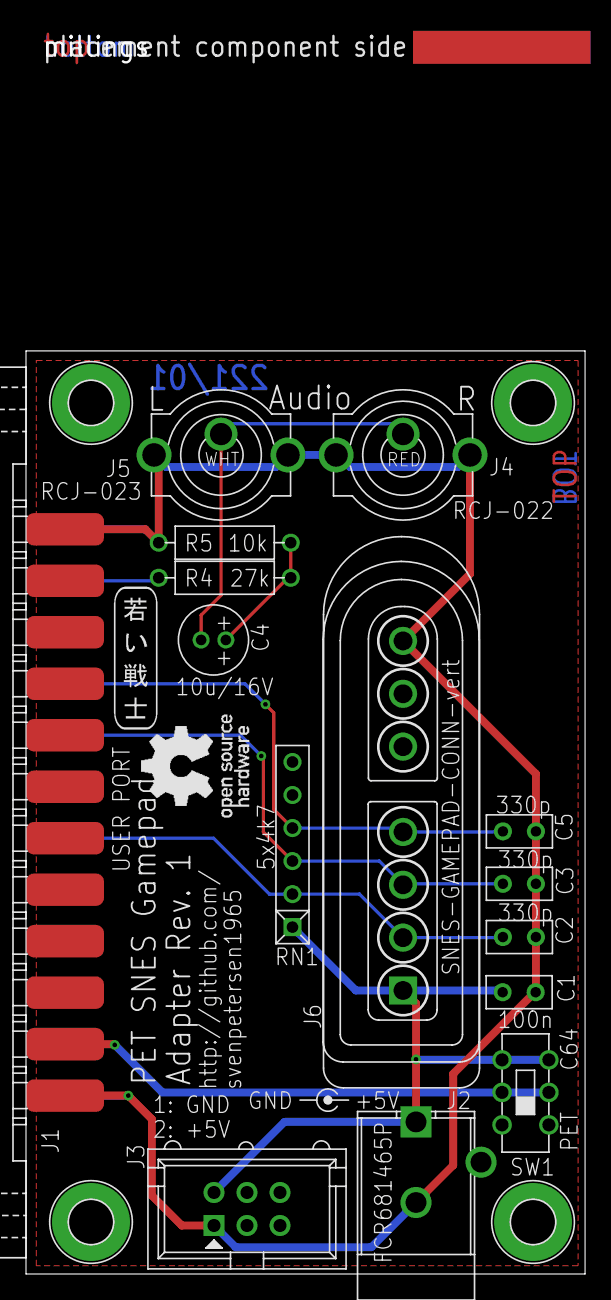
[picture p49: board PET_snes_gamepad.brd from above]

Board: 2 copper layers, 43.0 x 71.0 mm, 23 parts (0 on the bottom side), 9 nets.

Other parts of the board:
U$11: 2LAYER
U$22: PCB-TITLE/
U$26: SVEN_TAG
